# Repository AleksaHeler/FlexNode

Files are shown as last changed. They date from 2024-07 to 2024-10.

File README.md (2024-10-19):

# FlexNode

FlexNode is a DIY "smart home" system with a single hub and multiple flexible and customizable nodes.

## System Diagram

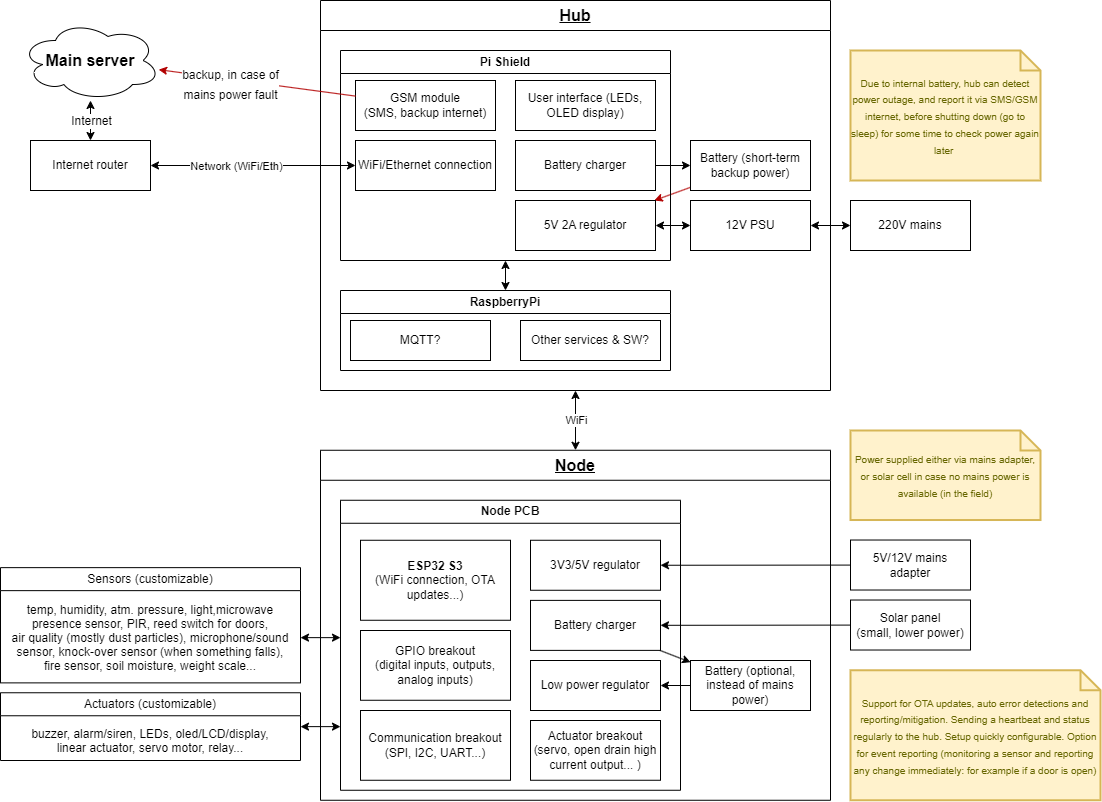
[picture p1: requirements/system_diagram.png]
system requirement diagram


### Node proof of concept

Some images during building:
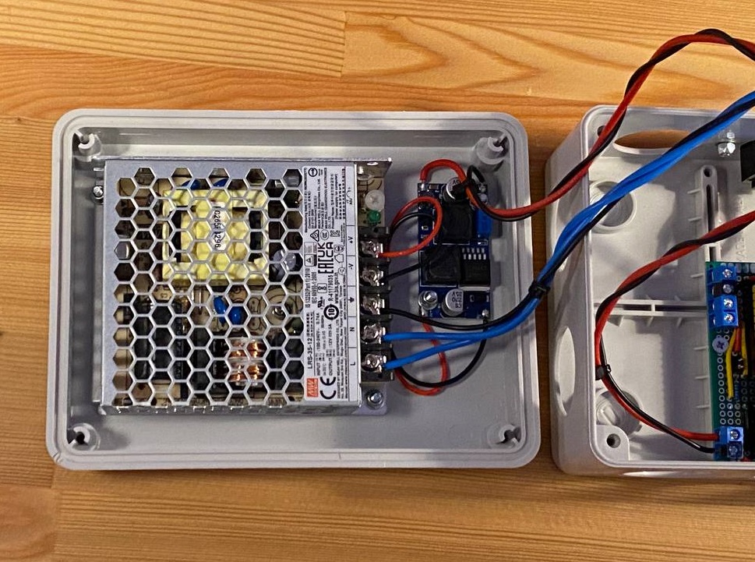
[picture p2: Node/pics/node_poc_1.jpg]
proof of concept build #1

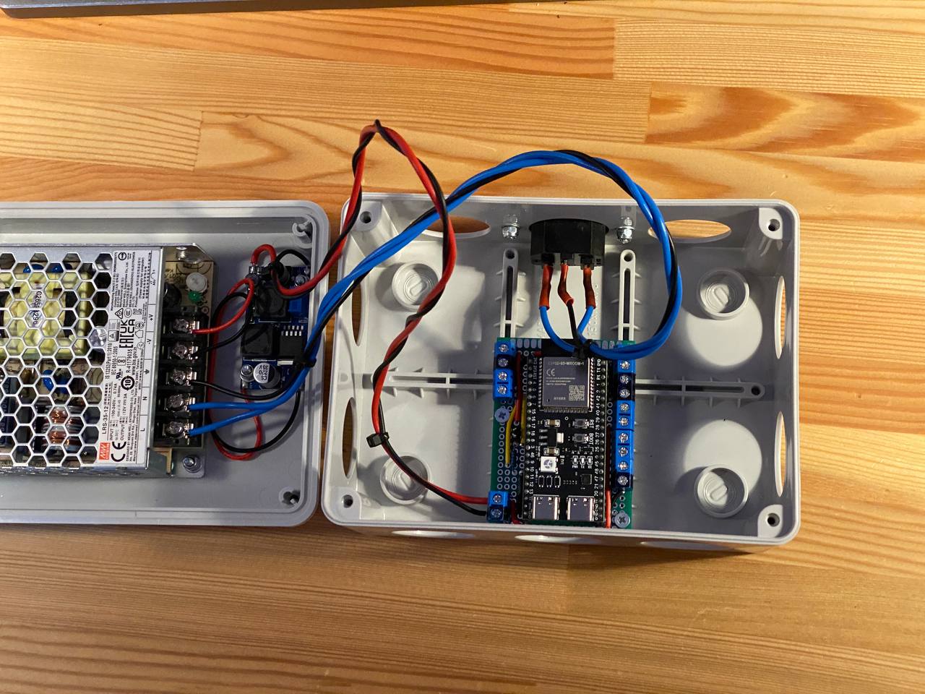
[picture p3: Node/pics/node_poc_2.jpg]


Grafana screenshots showing it in action:
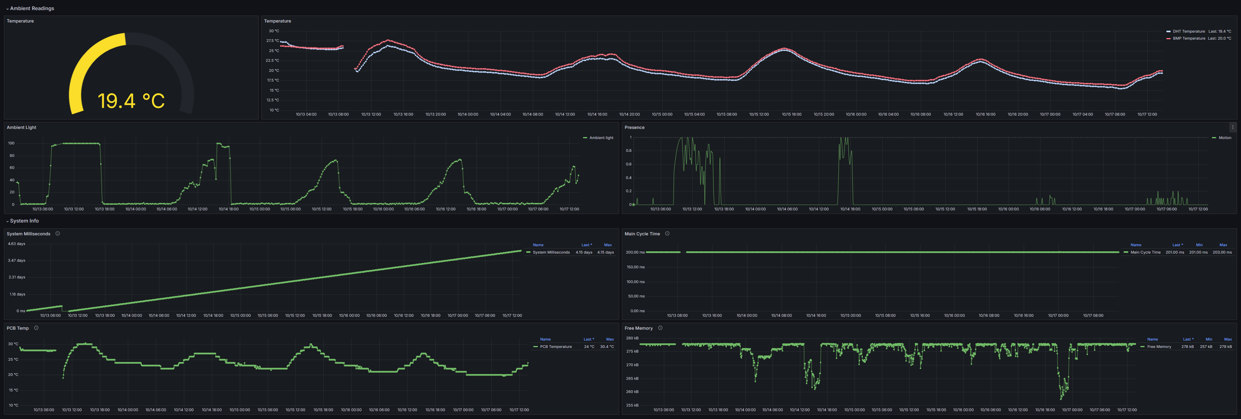
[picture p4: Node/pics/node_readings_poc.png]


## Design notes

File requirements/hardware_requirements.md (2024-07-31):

# Hardware requirements

## Hub
 - Shield for RaspberryPi
 - Integrated small battery, and on-board battery charger (what type of battery? how many cells? possibly small bike battery?)
   - On power loss, use backup battery to send warning of power outage
 - GSM module for SMS and backup internet
 - All in a single box, using wifi, or even ethernet connection to a router
 - Input voltage range for example 12-36V, which is stepped down to charge the battery and to run Pi. On power loss, able to detect
   main supply is out, but continue working on battery for some time to send last message

### Hub component selection
 - Battery?
 - Charger IC for the battery?
 - GSM module?
 - Power regulation, buck converter?
 - ...

## Node
 - Main processor: ESP32 S3 module
 - Option for adding a battery and a charger - find suitable ICs, and low power LDO regulator
 - How many cells (most likely one cell li-ion, 4.2V charging)
 - Input power from a small solar panel to charge the battery
 - All in a box (except solar cell, to be positioned at best angle)
 - Option to run in ultra low power mode (at least 1 month without any additional charge)
 - WiFi communication to the Hub + Over The Air updates (OTA)
 - Couple of on-board sensors and feedbacks
 - As many GPIO outputs as possible - for external sensors/actuators
 - All comms: SPI, I2C, UART... break out to connectors
 - What actuators will we have? What are the power requirements?
   - H bridge? servo output? DC motor output? Relay/SSR output? What will be on the PCB, and what connected externally within the box
 - Example sensor inputs (3x 1wire, 3x I2C, 4x ADC, 5x dig in):
   - temp - 1 wire
   - humidity - 1 wire
   - atm. pressure - I2C, 1 wire
   - light - analog input
   - microwave presence sensor - dig in
   - PIR - dig in
   - reed switch for doors - dig in
   - air quality (mostly dust particles) - I2C
   - microphone/sound sensor - analog input
   - knock-over sensor (when something falls) - dig in
   - fire sensor - dig in/ analog input
   - soil moisture - analog input
   - weight scale - I2C
 - Example actuator outputs (5x open drain, 1x PWM, I2C):
   - buzzer - dig out, open drain
   - alarm/siren - open drain
   - LEDs - dig out, open drain
   - oled/LCD/display - I2C
   - linear actuator - open drain
   - servo motor - PWM output
   - relay - open drain
 - Based on examples:
   - 6x digital inputs/outpus (with 1wire support)
   - 4x analog inputs
   - 4x open drain, high power outputs
   - 2x PWM, servo outputs

### Node component selection
 - [ESP32 S3 WROOM 1 N16R8](https://www.lcsc.com/product-detail/WiFi-Modules_Espressif-Systems-ESP32-S3-WROOM-1-N16R8_C2913202.html)
 - Battery management IC - [MCP73831T](https://www.lcsc.com/product-detail/span-style-background-color-ff0-Battery-span-Management_Microchip-Tech-MCP73831T-2ACI-OT_C424093.html)
 - LDO, low quiescent current 3v3 regulator - [TLV70433DBVR](https://www.lcsc.com/product-detail/Voltage-Regulators-Linear-Low-Drop-Out-span-style-background-color-ff0-LDO-span-Regulators_Texas-Instruments-TLV70433DBVR_C94917.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)
 - Low-Side Gate Driver for open drain outputs - [UCC27517](https://www.lcsc.com/product-detail/Gate-Drivers_Texas-Instruments-UCC27517DBVR_C99395.html)
 - Battery: 1 cell LiIon
 - Screw terminals
 - Battery

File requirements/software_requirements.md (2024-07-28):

# Software requirements

## Hub
 - RaspberryPi + DIY shield for Pi
 - On power loss, use backup battery to send warning of power outage
 - Use existing WiFi networks (but possibility to use GSM module for standalone operation)
 - Uploads all data to main server, which is hosted somewhere else
 
## Node
 - DIY PCB, with ESP32 S3 module
 - Many different sensor/actuator options
 - Option to run in ultra low power mode, with battery and solar panel options 
   (for installing in locations without power supply)
 - WiFi communication to the Hub
 - Modular - same PCB/HW, almost same SW (just config different) for all possible scenarios
 - Over The Air updates (OTA)
 - Option to monitor sensors constanly (alarm function)
 - Periodic wakeup, gather data, send to Hub
 - Configurable via simple config file
 - Sending a heartbeat signal to the hub if necessary, also status (starting up, shutting down...)
 - Auto error detections and mitigations (resets, sending a warning/error, self shutdown...)
 - Possible sensors: temp, humidity, atm. pressure, light, microwave presence sensor, PIR,
   reed switch for doors, air quality (mostly dust particles), microphone/sound sensor,
   knock-over sensor (when something falls), fire sensor, soil moisture, weight scale...
 - Possible actuators: buzzer, alarm/siren, LEDs, oled/LCD/display, linear actuator, servo motor, relay...

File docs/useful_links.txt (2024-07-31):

https://docs.espressif.com/projects/esp-idf/en/stable/esp32s3/api-reference/system/sleep_modes.html

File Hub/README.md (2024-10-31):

# Hub

Raspberry Pi 3 B+, running NodeRed, InfluxDB and Grafana.

## System requirement

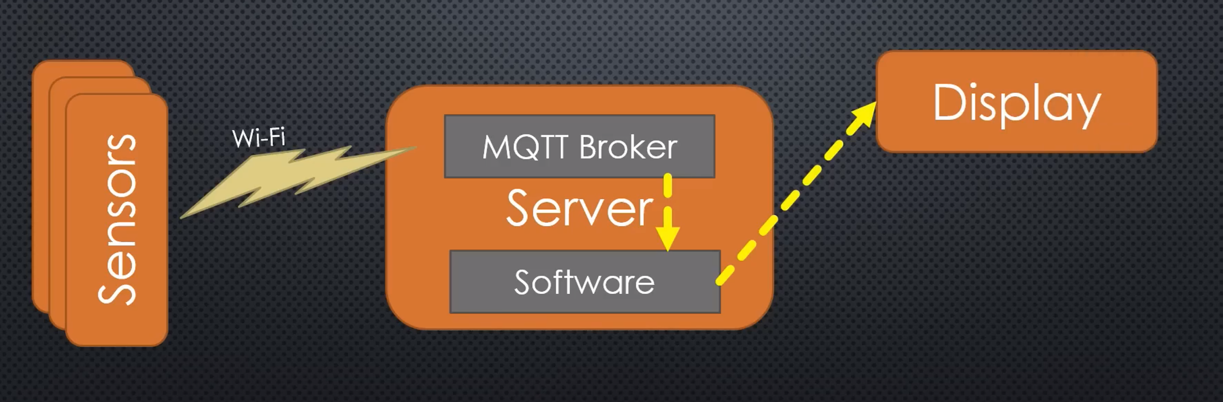
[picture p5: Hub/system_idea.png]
System reference idea


## Setup procedure

Taken from [this video](https://www.youtube.com/watch?v=I4alYbgDi4I&list=PL3XBzmAj53RnezxZ_uq8YMymURnnLTqZP&index=9)

- install raspbian lite 64bit
- enable ssh, enter wifi data and username an password
- sudo apt-get update
- sudo apt-get dist-upgrade

- now follow peter scargill's instructions for his script
- apps:
  - quiet
  - prereq
  - mosquitto
  - apache
  - nodenew
  - java
  - phpsysinfo
  - modpass
  - addindex
  - rpiclone
  - log2ram
  - grafana
  - wolfram
  - office

- sudo nano /etc/influxdb/influxdb.conf (HTTP enable, and bind to standard port)
- create admin user
- check if grafana and nodered work
- todo: change from default ports, to use url/grafana and url/nodered (not port :3000, that should be blocked)

- Hearbeat signal / watchdog
  https://www.youtube.com/watch?v=IGB2eRvhvB0&list=PL3XBzmAj53RnezxZ_uq8YMymURnnLTqZP&index=10

- Add users to MQTT (for esp32 that will be connected) with command:
  > cd /etc/mosquitto/
  > mosquitto_passwd -c passwords user
  Now you can use this command to add additional users to the file:
  > mosquitto_passwd -b passwords user password
  And check all the passwords:
  > cat passwords

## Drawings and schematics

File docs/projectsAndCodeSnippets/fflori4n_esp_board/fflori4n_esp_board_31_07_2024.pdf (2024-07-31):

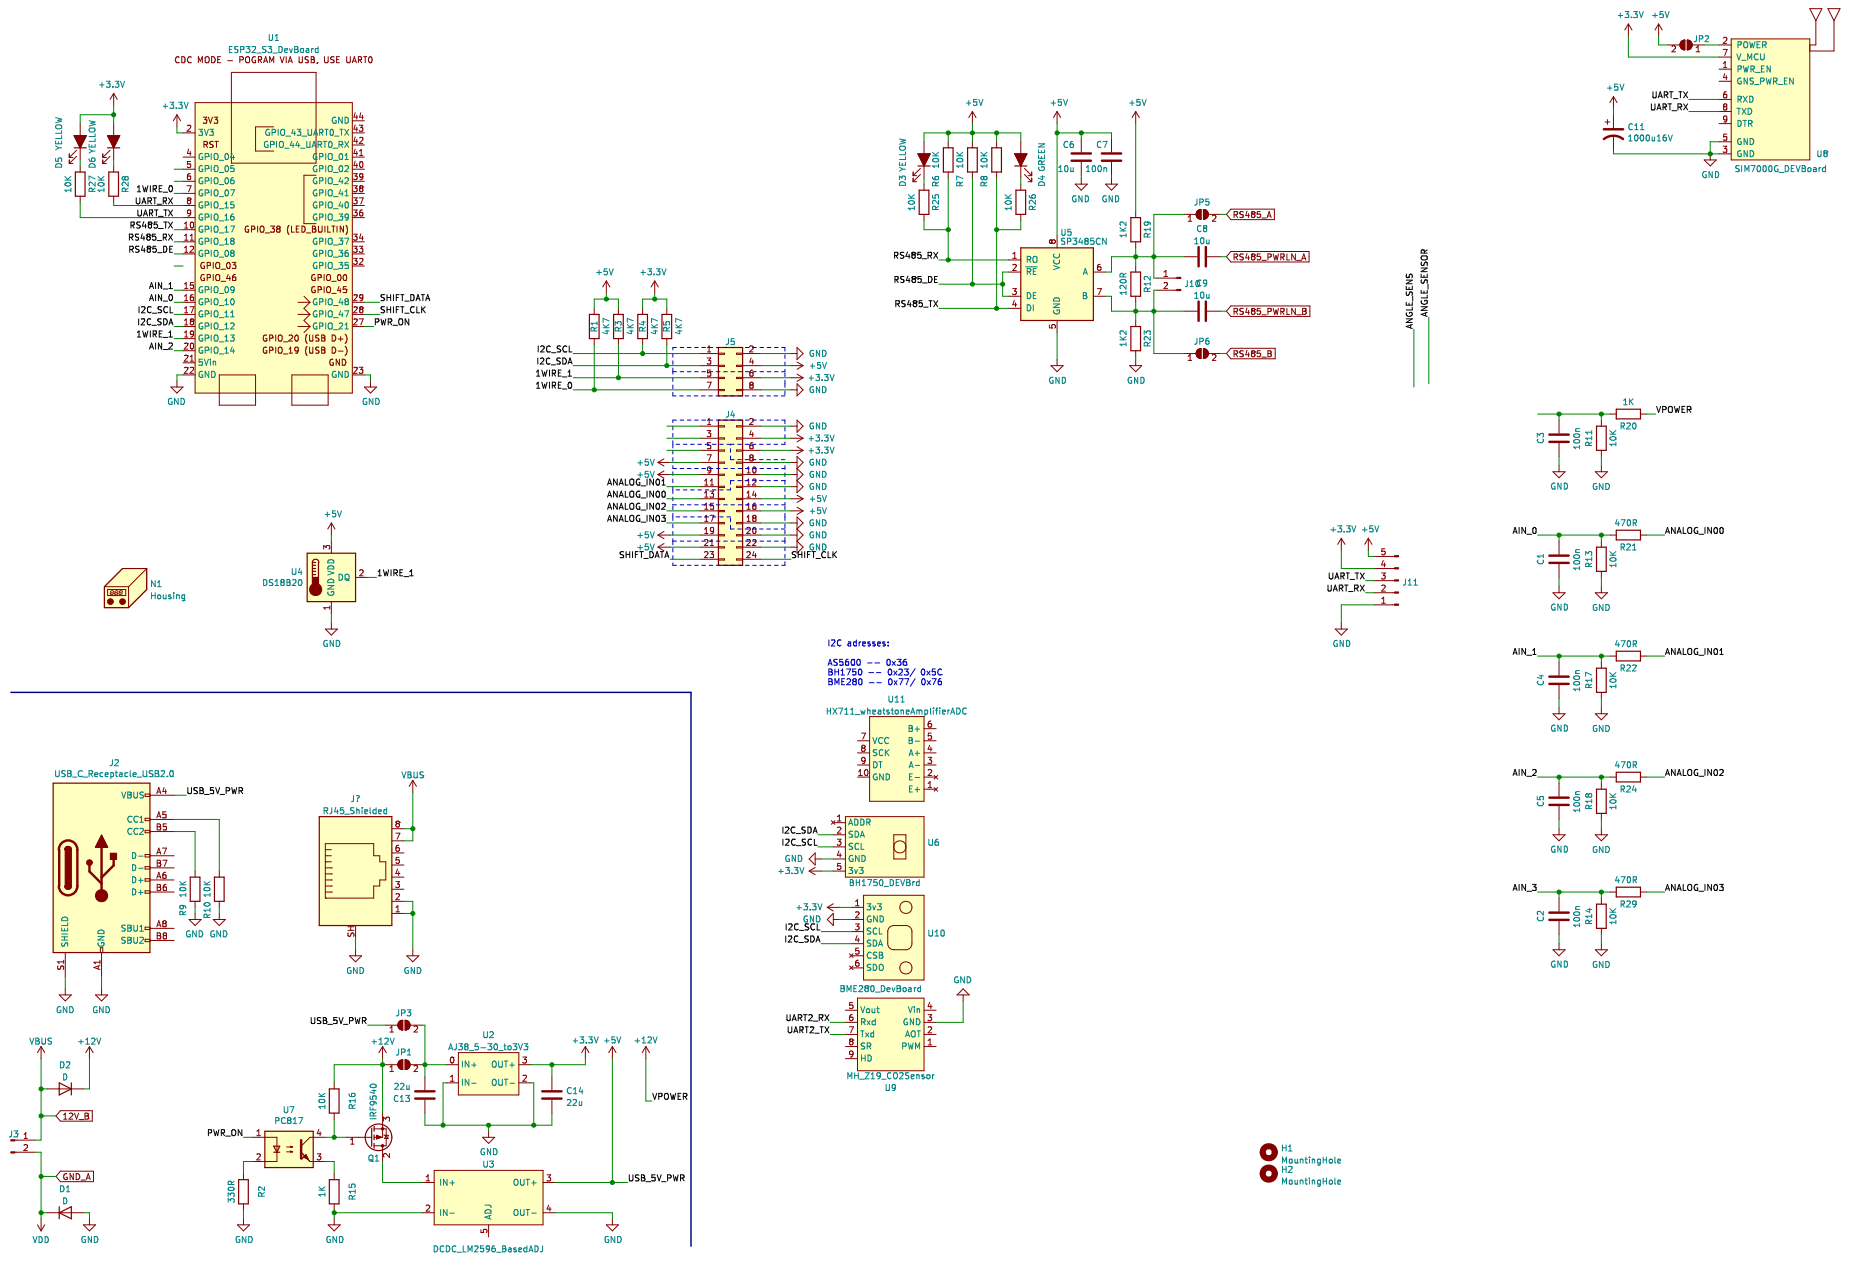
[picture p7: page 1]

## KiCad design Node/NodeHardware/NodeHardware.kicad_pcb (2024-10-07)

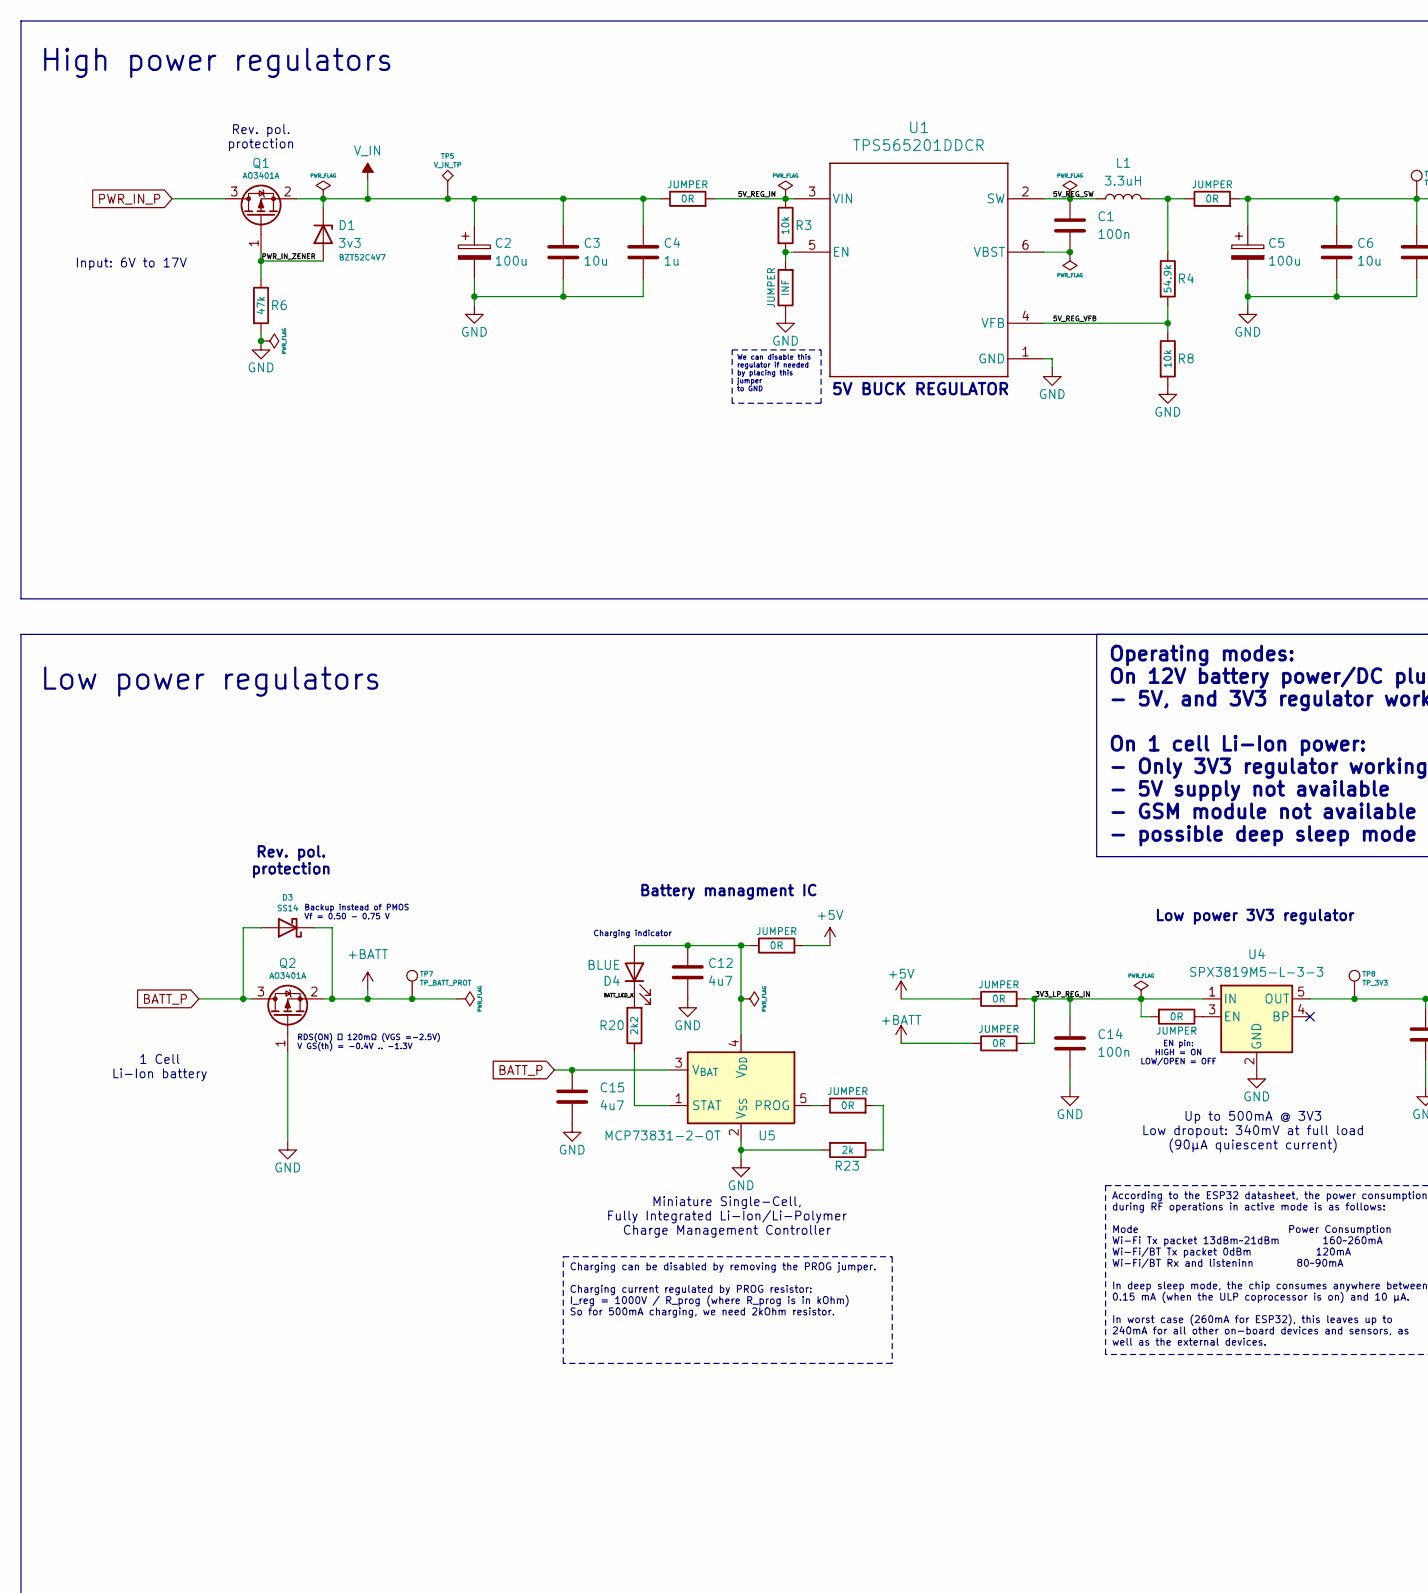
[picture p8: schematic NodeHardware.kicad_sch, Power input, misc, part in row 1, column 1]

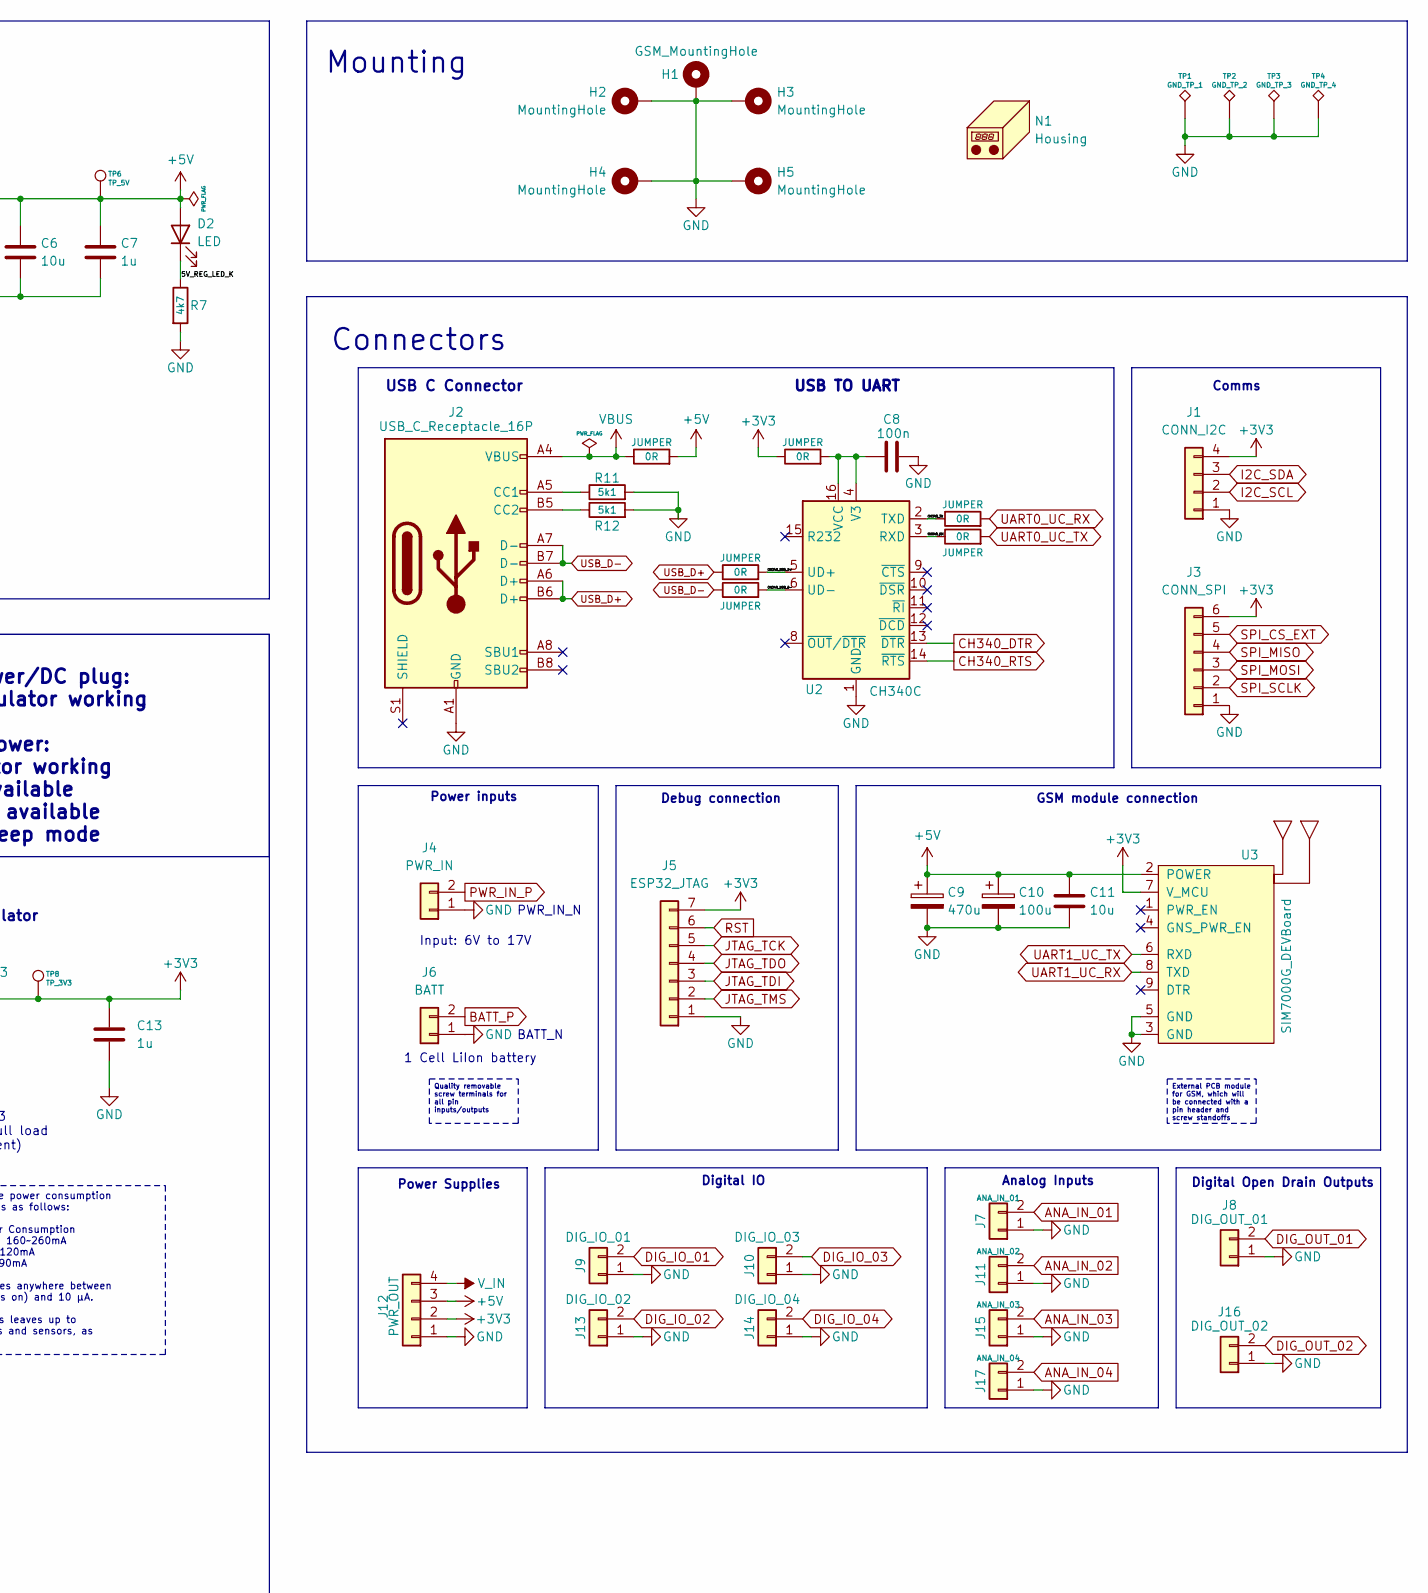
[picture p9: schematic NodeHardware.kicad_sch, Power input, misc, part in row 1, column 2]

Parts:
C1, C8, C14: 100n; C_0805_2012Metric
C2, C5, C10: 100u; CP_Elec_6.3x7.7
C3, C6, C11: 10u; C_0805_2012Metric
C4, C7, C13: 1u; C_0805_2012Metric
C9: 470u; CP_Elec_6.3x7.7
C12, C15: 4u7; C_0805_2012Metric
D1: 3v3; D_SOD-123; Part Name BZT52C4V7
D2: LED; LED_1210_3225Metric
D3: SS14; D_SMA
D4: BLUE; LED_1210_3225Metric
H1: GSM_MountingHole; MountingHole_3.2mm_M3_Pad_Via
H2, H3, H4, H5: MountingHole; MountingHole_3.2mm_M3_Pad_Via
J1: CONN_I2C; TerminalBlock_bornier-4_P5.08mm
J2: USB_C_Receptacle_16P; USB_C_Receptacle_G-Switch_GT-USB-7010ASV
J3: CONN_SPI; TerminalBlock_bornier-6_P5.08mm
J4: PWR_IN; TerminalBlock_bornier-2_P5.08mm
J5: ESP32_JTAG; PinHeader_1x07_P2.54mm_Vertical
J6: BATT; TerminalBlock_bornier-2_P5.08mm
J7: ANA_IN_01; TerminalBlock_bornier-2_P5.08mm
J8: DIG_OUT_01; TerminalBlock_bornier-2_P5.08mm
J9: DIG_IO_01; TerminalBlock_bornier-2_P5.08mm
J10: DIG_IO_03; TerminalBlock_bornier-2_P5.08mm
J11: ANA_IN_02; TerminalBlock_bornier-2_P5.08mm
J12: PWR_OUT; TerminalBlock_bornier-4_P5.08mm
J13: DIG_IO_02; TerminalBlock_bornier-2_P5.08mm
J14: DIG_IO_04; TerminalBlock_bornier-2_P5.08mm
J15: ANA_IN_03; TerminalBlock_bornier-2_P5.08mm
J16: DIG_OUT_02; TerminalBlock_bornier-2_P5.08mm
J17: ANA_IN_04; TerminalBlock_bornier-2_P5.08mm
L1: 3.3uH; L_6.3x6.3_H3
N1: Housing; PlasticEnclosure_150x110x70
Q1, Q2: AO3401A; SOT-23
R1, R2, R9, R10, R13, R14, R15, R16, R17, R18, R19, R21, R22: 0R; R_0805_2012Metric
R3, R8: 10k; R_0805_2012Metric
R4: 54.9k; R_0805_2012Metric
R5: INF; R_0805_2012Metric
R6: 47k; R_0805_2012Metric
R7: 4k7; R_0805_2012Metric
R11, R12: 5k1; R_0805_2012Metric
R20: 2k2; R_0805_2012Metric
R23: 2k; R_0805_2012Metric
TP1: GND_TP_1; TestPoint_Pad_D2.0mm
TP2: GND_TP_2; TestPoint_Pad_D2.0mm
TP3: GND_TP_3; TestPoint_Pad_D2.0mm
TP4: GND_TP_4; TestPoint_Pad_D2.0mm
TP5: V_IN_TP; TestPoint_Pad_D2.0mm
TP6: TP_5V; TestPoint_Pad_D2.0mm
TP7: TP_BATT_PROT; TestPoint_Pad_D2.0mm
TP8: TP_3V3; TestPoint_Pad_D2.0mm
U1: TPS565201DDCR; TPS565201DDCR_L
U2: CH340C; SOIC-16_3.9x9.9mm_P1.27mm
U3: SIM7000G_DEVBoard; sim7000G_dev_board_rev3
U4: SPX3819M5-L-3-3; SOT-23-5
U5: MCP73831-2-OT; SOT-23-5

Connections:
+3V3: C13.1, J1.4, J3.6, J5.7, J12.2, R10.1, TP8.1, U3.7 (V_MCU), U4.5 (OUT); also elsewhere on the board
+5V: C5.1, C6.1, C7.1, C9.1, C10.1, C11.1, D2.2 (A), J12.3, R2.2, R9.2, R17.2, R18.1, TP6.1, U3.2 (POWER); also elsewhere on the board
+BATT: D3.1 (K), Q2.2 (S), R21.1, TP7.1; also elsewhere on the board
/3V3_LP_REG_IN: C14.1, R18.2, R19.2, R21.2, U4.1 (IN)
/5V_REG_IN: R1.2, R3.1, U1.3 (VIN)
/5V_REG_LED_K: D2.1 (K), R7.1
/5V_REG_SW: C1.1, L1.1, U1.2 (SW)
/5V_REG_VFB: R4.2, R8.1, U1.4 (VFB)
/BATT_LED_K: D4.1 (K), R20.2
/CH340_RX: R14.1, U2.3 (RXD)
/CH340_TX: R13.1, U2.2 (TXD)
/CH340_USB_D+: R15.2, U2.5 (UD+)
/CH340_USB_D-: R16.2, U2.6 (UD-)
/PWR_IN_ZENER: D1.2 (A), Q1.1 (G), R6.1
ANA_IN_01: J7.2; also elsewhere on the board
ANA_IN_02: J11.2; also elsewhere on the board
ANA_IN_03: J15.2; also elsewhere on the board
ANA_IN_04: J17.2; also elsewhere on the board
BATT_P: C15.1, D3.2 (A), J6.2, Q2.3 (D), U5.3 (V_{BAT})
CH340_DTR: U2.13 (~DTR); also elsewhere on the board
CH340_RTS: U2.14 (~RTS); also elsewhere on the board
DIG_IO_01: J9.2; also elsewhere on the board
DIG_IO_02: J13.2; also elsewhere on the board
DIG_IO_03: J10.2; also elsewhere on the board
DIG_IO_04: J14.2; also elsewhere on the board
DIG_OUT_01: J8.2; also elsewhere on the board
DIG_OUT_02: J16.2; also elsewhere on the board
GND: C2.2, C3.2, C4.2, C5.2, C6.2, C7.2, C8.2, C9.2, C10.2, C11.2, C12.2, C13.2, C14.2, C15.2, H1.1, H2.1, H3.1, H4.1, H5.1, J1.1, J2.A1 (GND), J2.A12 (GND), J2.B1 (GND), J2.B12 (GND), J3.1, J4.1, J5.1, J6.1, J7.1, J8.1, J9.1, J10.1, J11.1, J12.1, J13.1, J14.1, J15.1, J16.1, J17.1, Q2.1 (G), R5.1, R6.2, R7.2, R8.2, R11.2, R12.2, R23.2, TP1.1, TP2.1, TP3.1, TP4.1, U1.1 (GND), U2.1 (GND), U3.3 (GND), U3.5 (GND), U4.2 (GND), U5.2 (V_{SS}); also elsewhere on the board
I2C_SCL: J1.2; also elsewhere on the board
I2C_SDA: J1.3; also elsewhere on the board
JTAG_TCK: J5.5; also elsewhere on the board
JTAG_TDI: J5.3; also elsewhere on the board
JTAG_TDO: J5.4; also elsewhere on the board
JTAG_TMS: J5.2; also elsewhere on the board
unnamed: C12.1, D4.2 (A), R17.1, U5.4 (V_{DD})
unnamed: J2.A5 (CC1), R11.1
unnamed: J2.B5 (CC2), R12.1
unnamed: L1.2, R2.1, R4.1
unnamed: R22.2, R23.1
unnamed: R3.2, R5.2, U1.5 (EN)
unnamed: C1.2, U1.6 (VBST)
unnamed: C8.1, R10.2, U2.4 (V3), U2.16 (VCC)
unnamed: R19.1, U4.3 (EN)
unnamed: R22.1, U5.5 (PROG)
unnamed: R20.1, U5.1 (STAT)
PWR_IN_P: J4.2, Q1.3 (D)
RST: J5.6; also elsewhere on the board
SPI_CS_EXT: J3.5; also elsewhere on the board
SPI_MISO: J3.4; also elsewhere on the board
SPI_MOSI: J3.3; also elsewhere on the board
SPI_SCLK: J3.2; also elsewhere on the board
UART0_UC_RX: R13.2; also elsewhere on the board
UART0_UC_TX: R14.2; also elsewhere on the board
UART1_UC_RX: U3.8 (TXD); also elsewhere on the board
UART1_UC_TX: U3.6 (RXD); also elsewhere on the board
USB_D+: J2.A6 (D+), J2.B6 (D+), R15.1; also elsewhere on the board
USB_D-: J2.A7 (D-), J2.B7 (D-), R16.1; also elsewhere on the board
VBUS: J2.A4 (VBUS), J2.A9 (VBUS), J2.B4 (VBUS), J2.B9 (VBUS), R9.1
V_IN: C2.1, C3.1, C4.1, D1.1 (K), J12.4, Q1.2 (S), R1.1, TP5.1; also elsewhere on the board

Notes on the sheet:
We can disable this regulator if needed by placing this jumper to GND
External PCB module for GSM, which will be connected with a pin header and screw standoffs
Quality removable screw terminals for all pin inputs/outputs
Charging can be disabled by removing the PROG jumper. Charging current regulated by PROG resistor: I_reg = 1000V / R_prog (where R_prog is in kOhm) So for 500mA charging, we need 2kOhm resistor.
Operating modes: On 12V battery power/DC plug: - 5V, and 3V3 regulator working On 1 cell Li-Ion power: - Only 3V3 regulator working - 5V supply not available - GSM module not available - possible deep sleep mode
According to the ESP32 datasheet, the power consumption during RF operations in active mode is as follows: Mode Power Consumption Wi-Fi Tx packet 13dBm~21dBm 160~260mA Wi-Fi/BT Tx packet 0dBm 120mA Wi-Fi/BT Rx and listeninn 80~90mA In deep sleep mode, the chip consumes anywhere between 0.15 mA (whe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
Battery managment IC
1 Cell Li-Ion battery
Power Supplies
Charging indicator
Connectors
Low power 3V3 regulator
PWR_IN_N
Debug connection
Input: 6V to 17V
Power inputs
USB TO UART
Rev. pol. protection
Analog Inputs
Backup instead of PMOS Vf = 0.50 - 0.75 V
Comms
5V BUCK REGULATOR
EN pin: HIGH = ON LOW/OPEN = OFF
USB C Connector
RDS(ON) ＜ 120mΩ (VGS =-2.5V) V GS(th) = -0.4V .. -1.3V
GSM module connection
Low power regulators
Digital IO
1 Cell LiIon battery
BATT_N
Mounting
Digital Open Drain Outputs
High power regulators
Up to 500mA @ 3V3 Low dropout: 340mV at full load (90μA quiescent current)
Miniature Single-Cell, Fully Integrated Li-Ion/Li-Polymer Charge Management Controller

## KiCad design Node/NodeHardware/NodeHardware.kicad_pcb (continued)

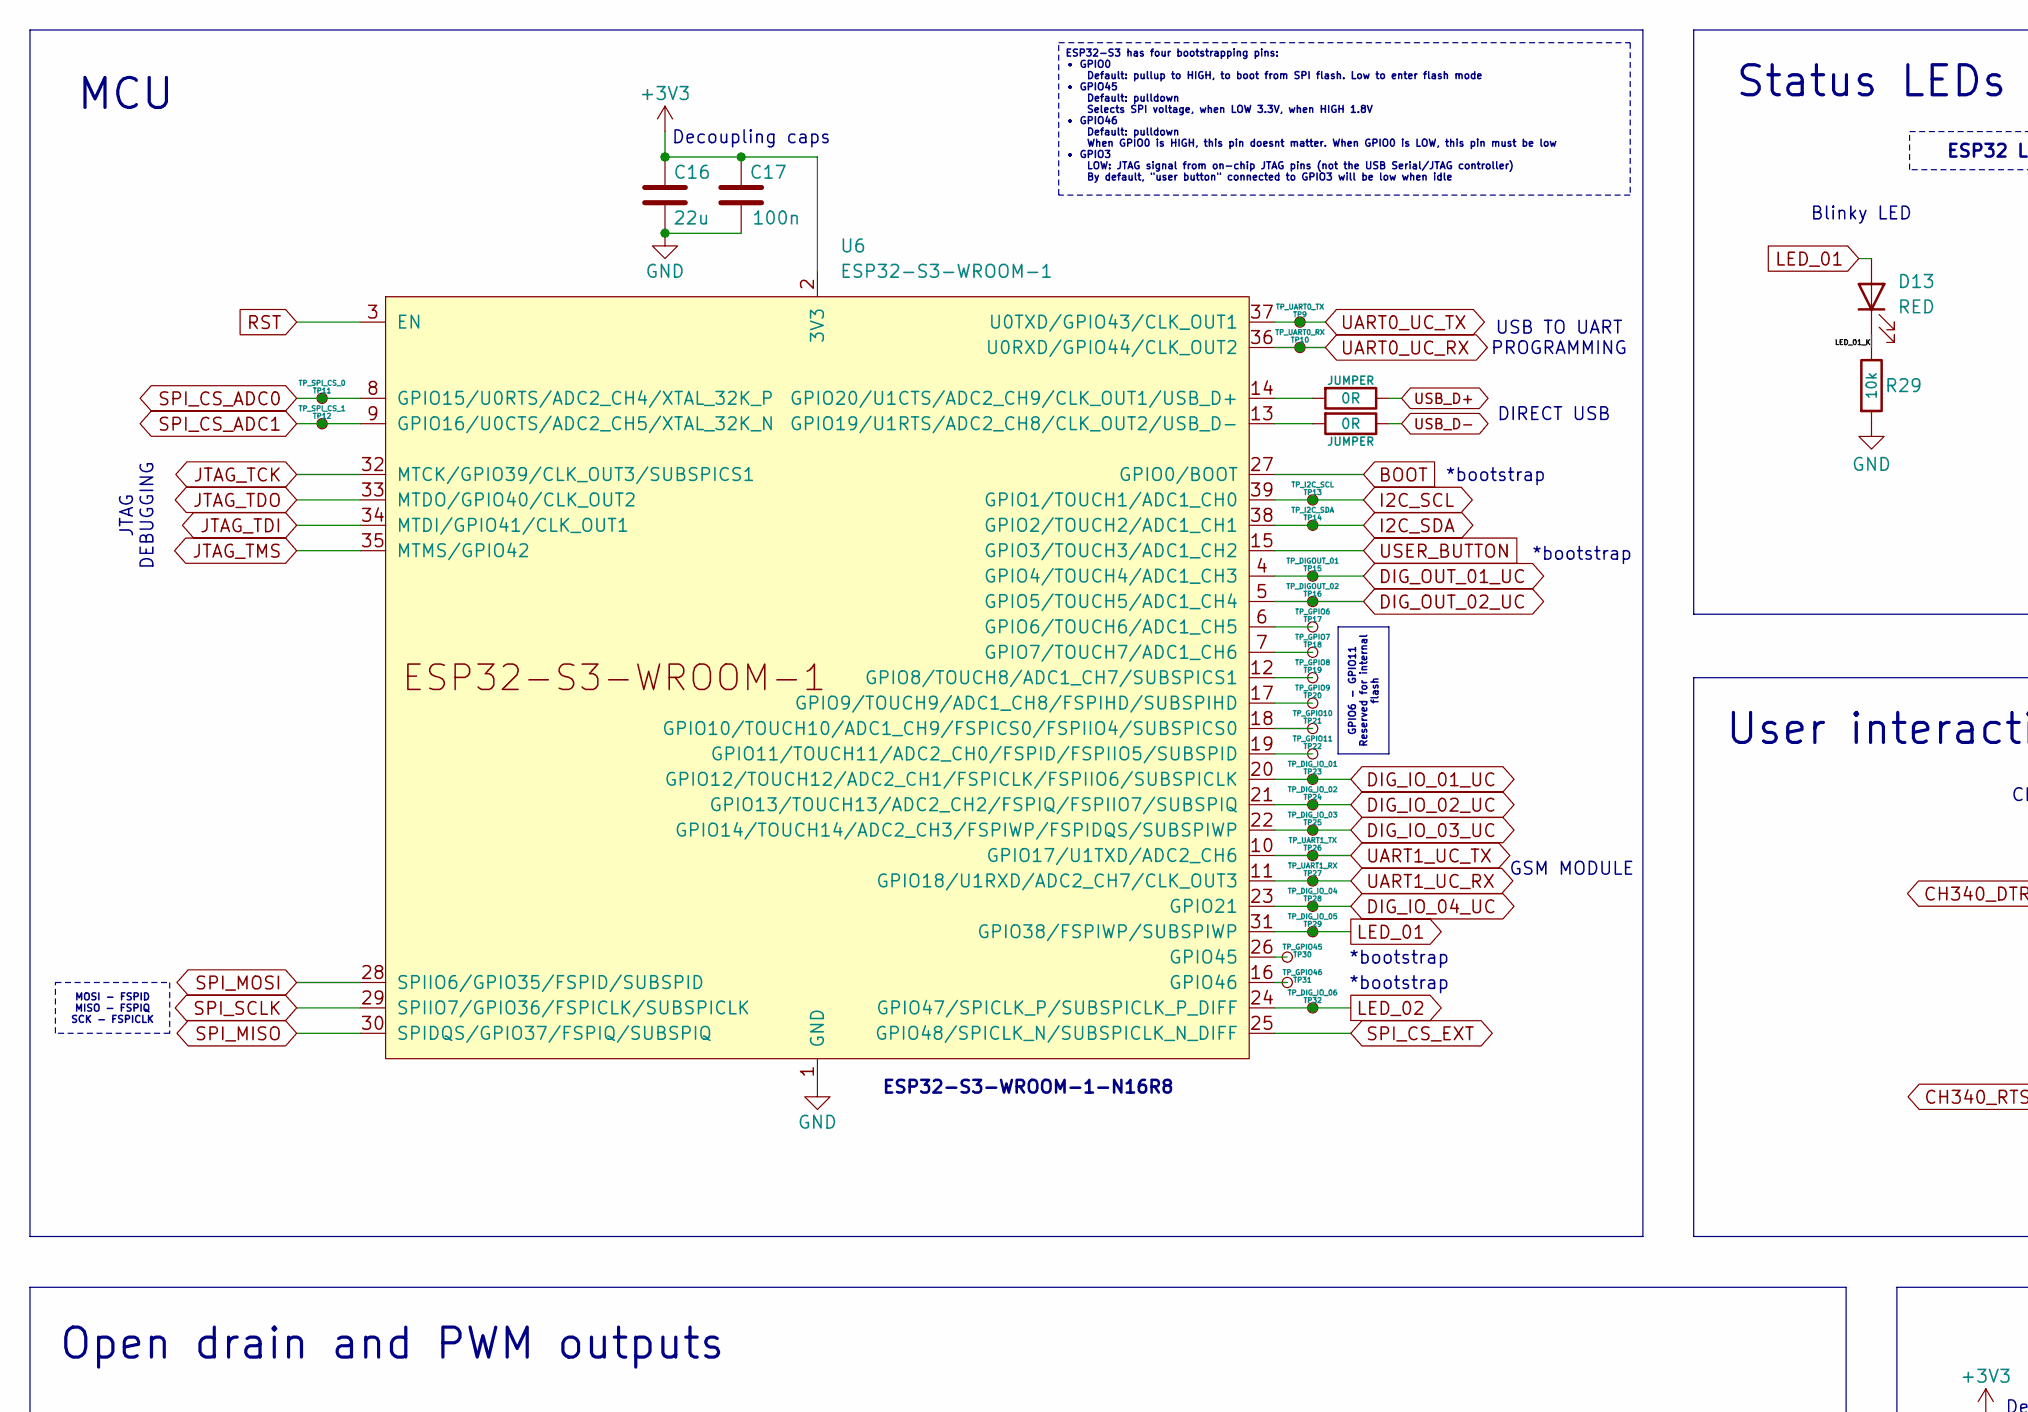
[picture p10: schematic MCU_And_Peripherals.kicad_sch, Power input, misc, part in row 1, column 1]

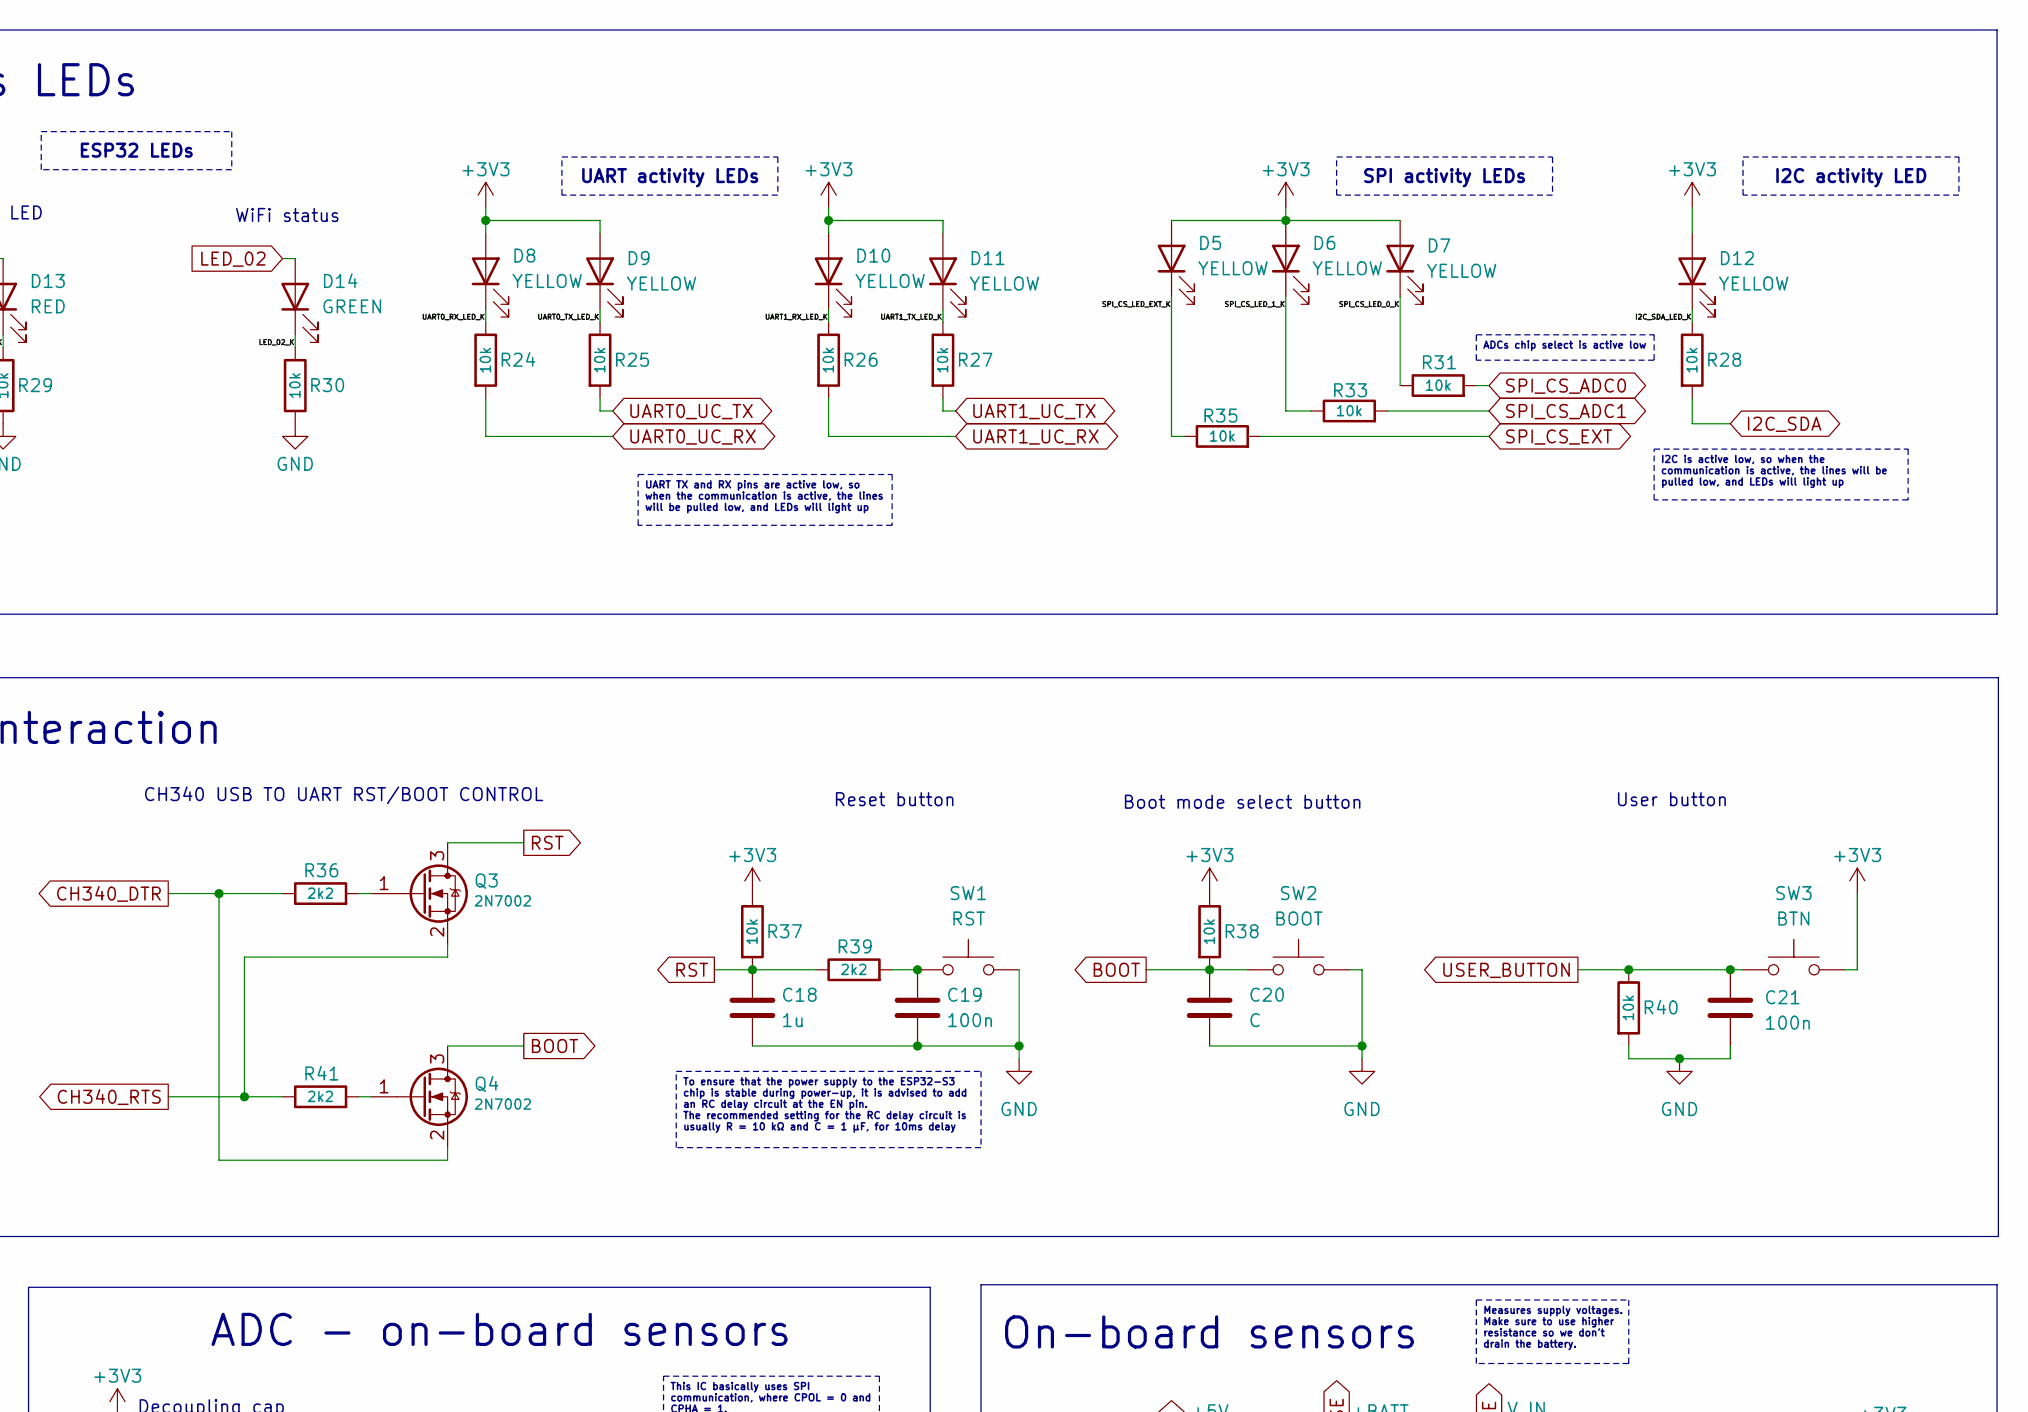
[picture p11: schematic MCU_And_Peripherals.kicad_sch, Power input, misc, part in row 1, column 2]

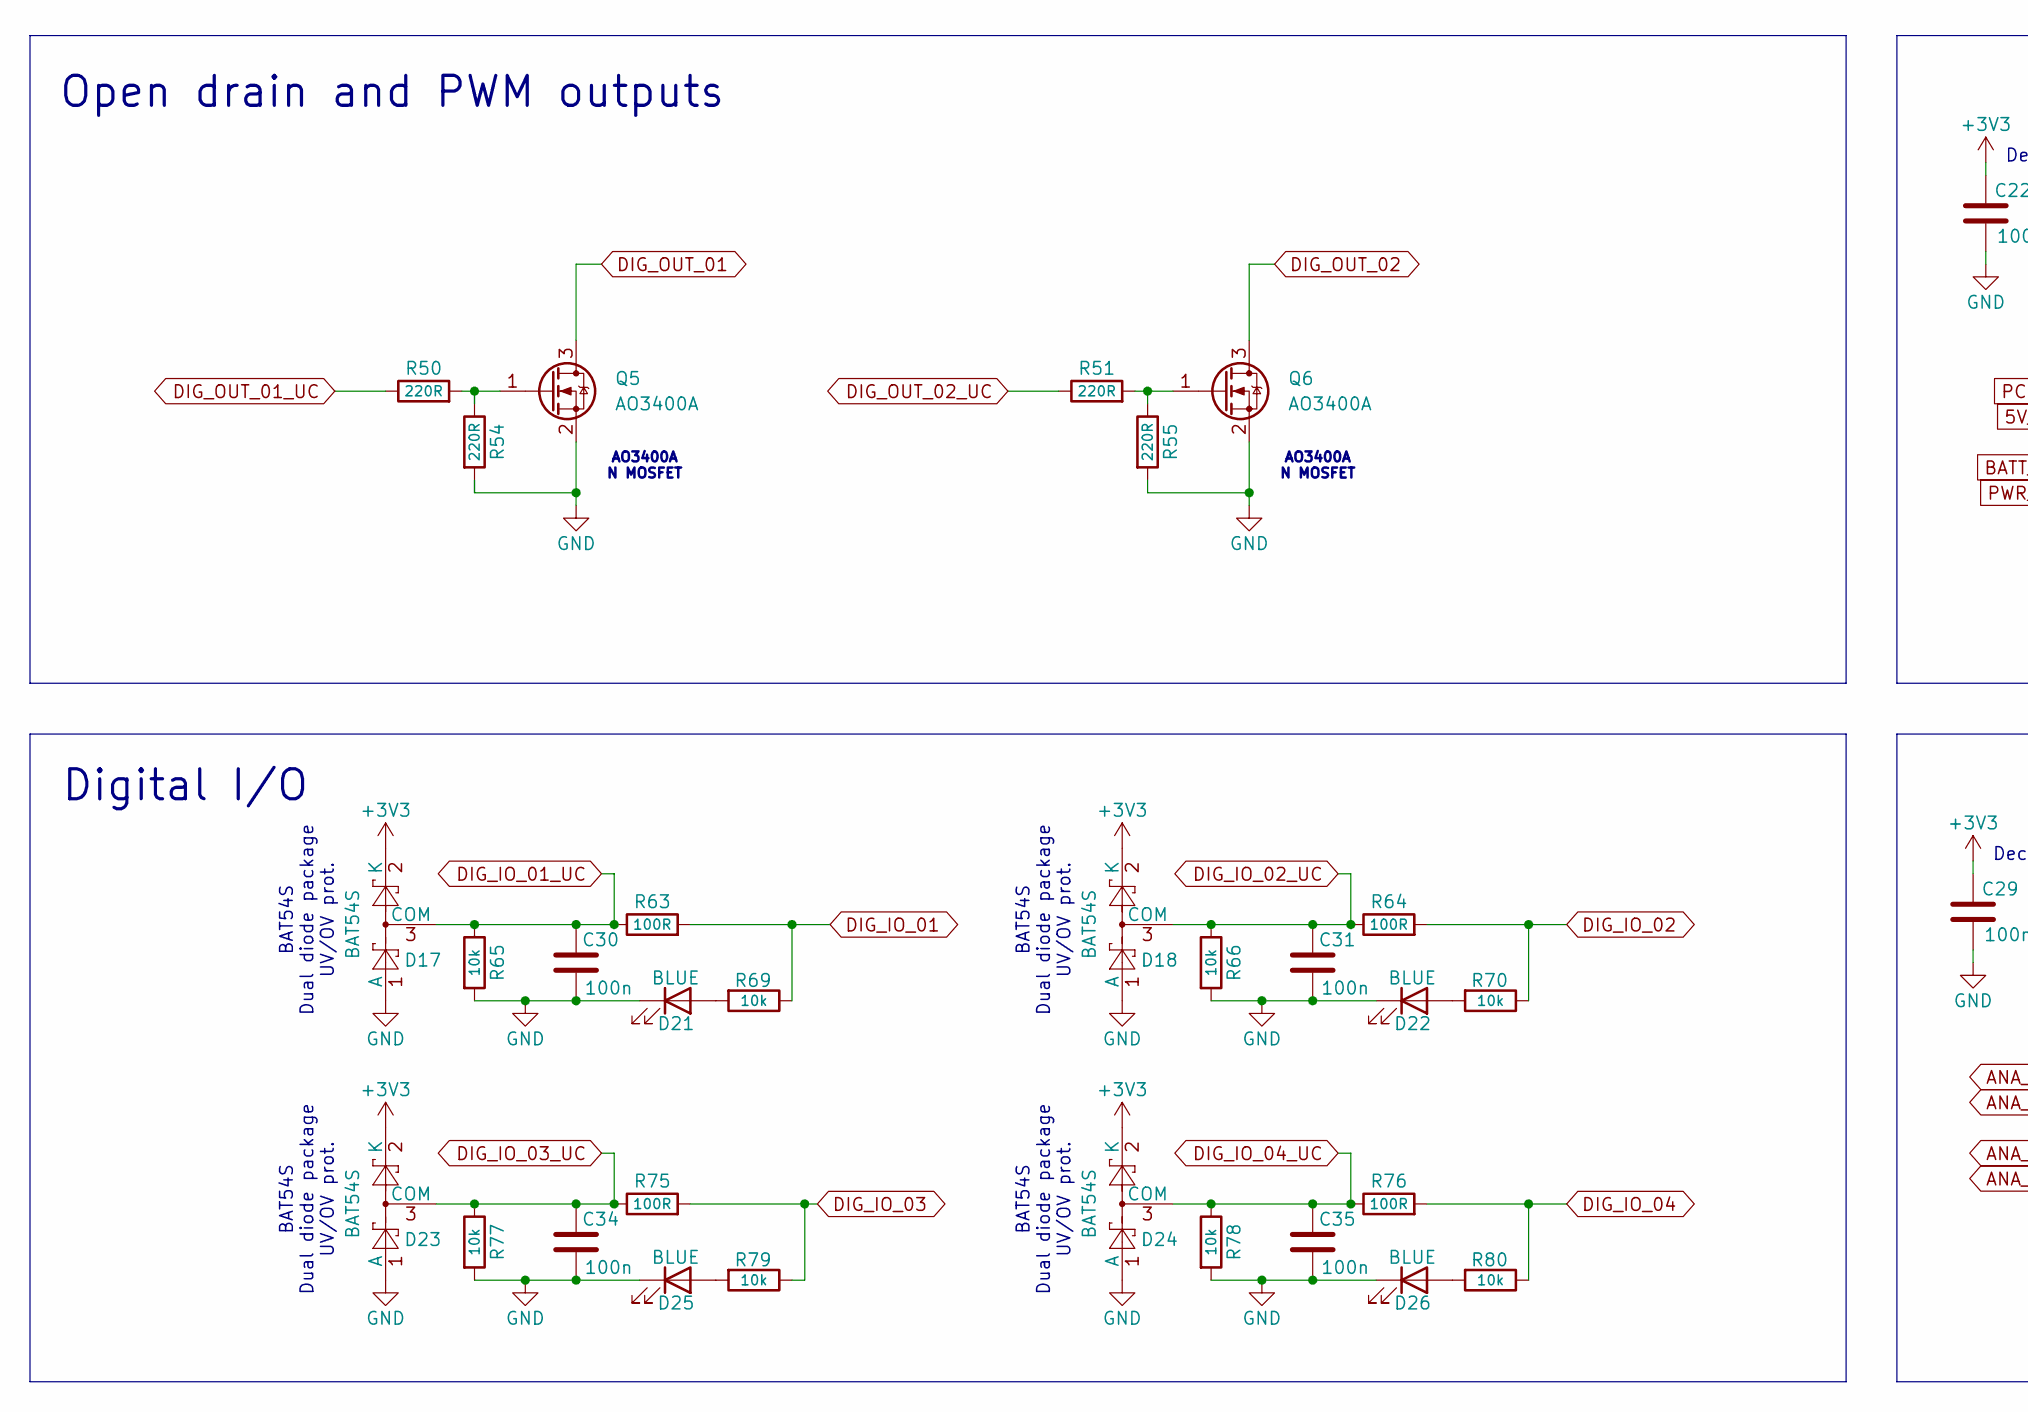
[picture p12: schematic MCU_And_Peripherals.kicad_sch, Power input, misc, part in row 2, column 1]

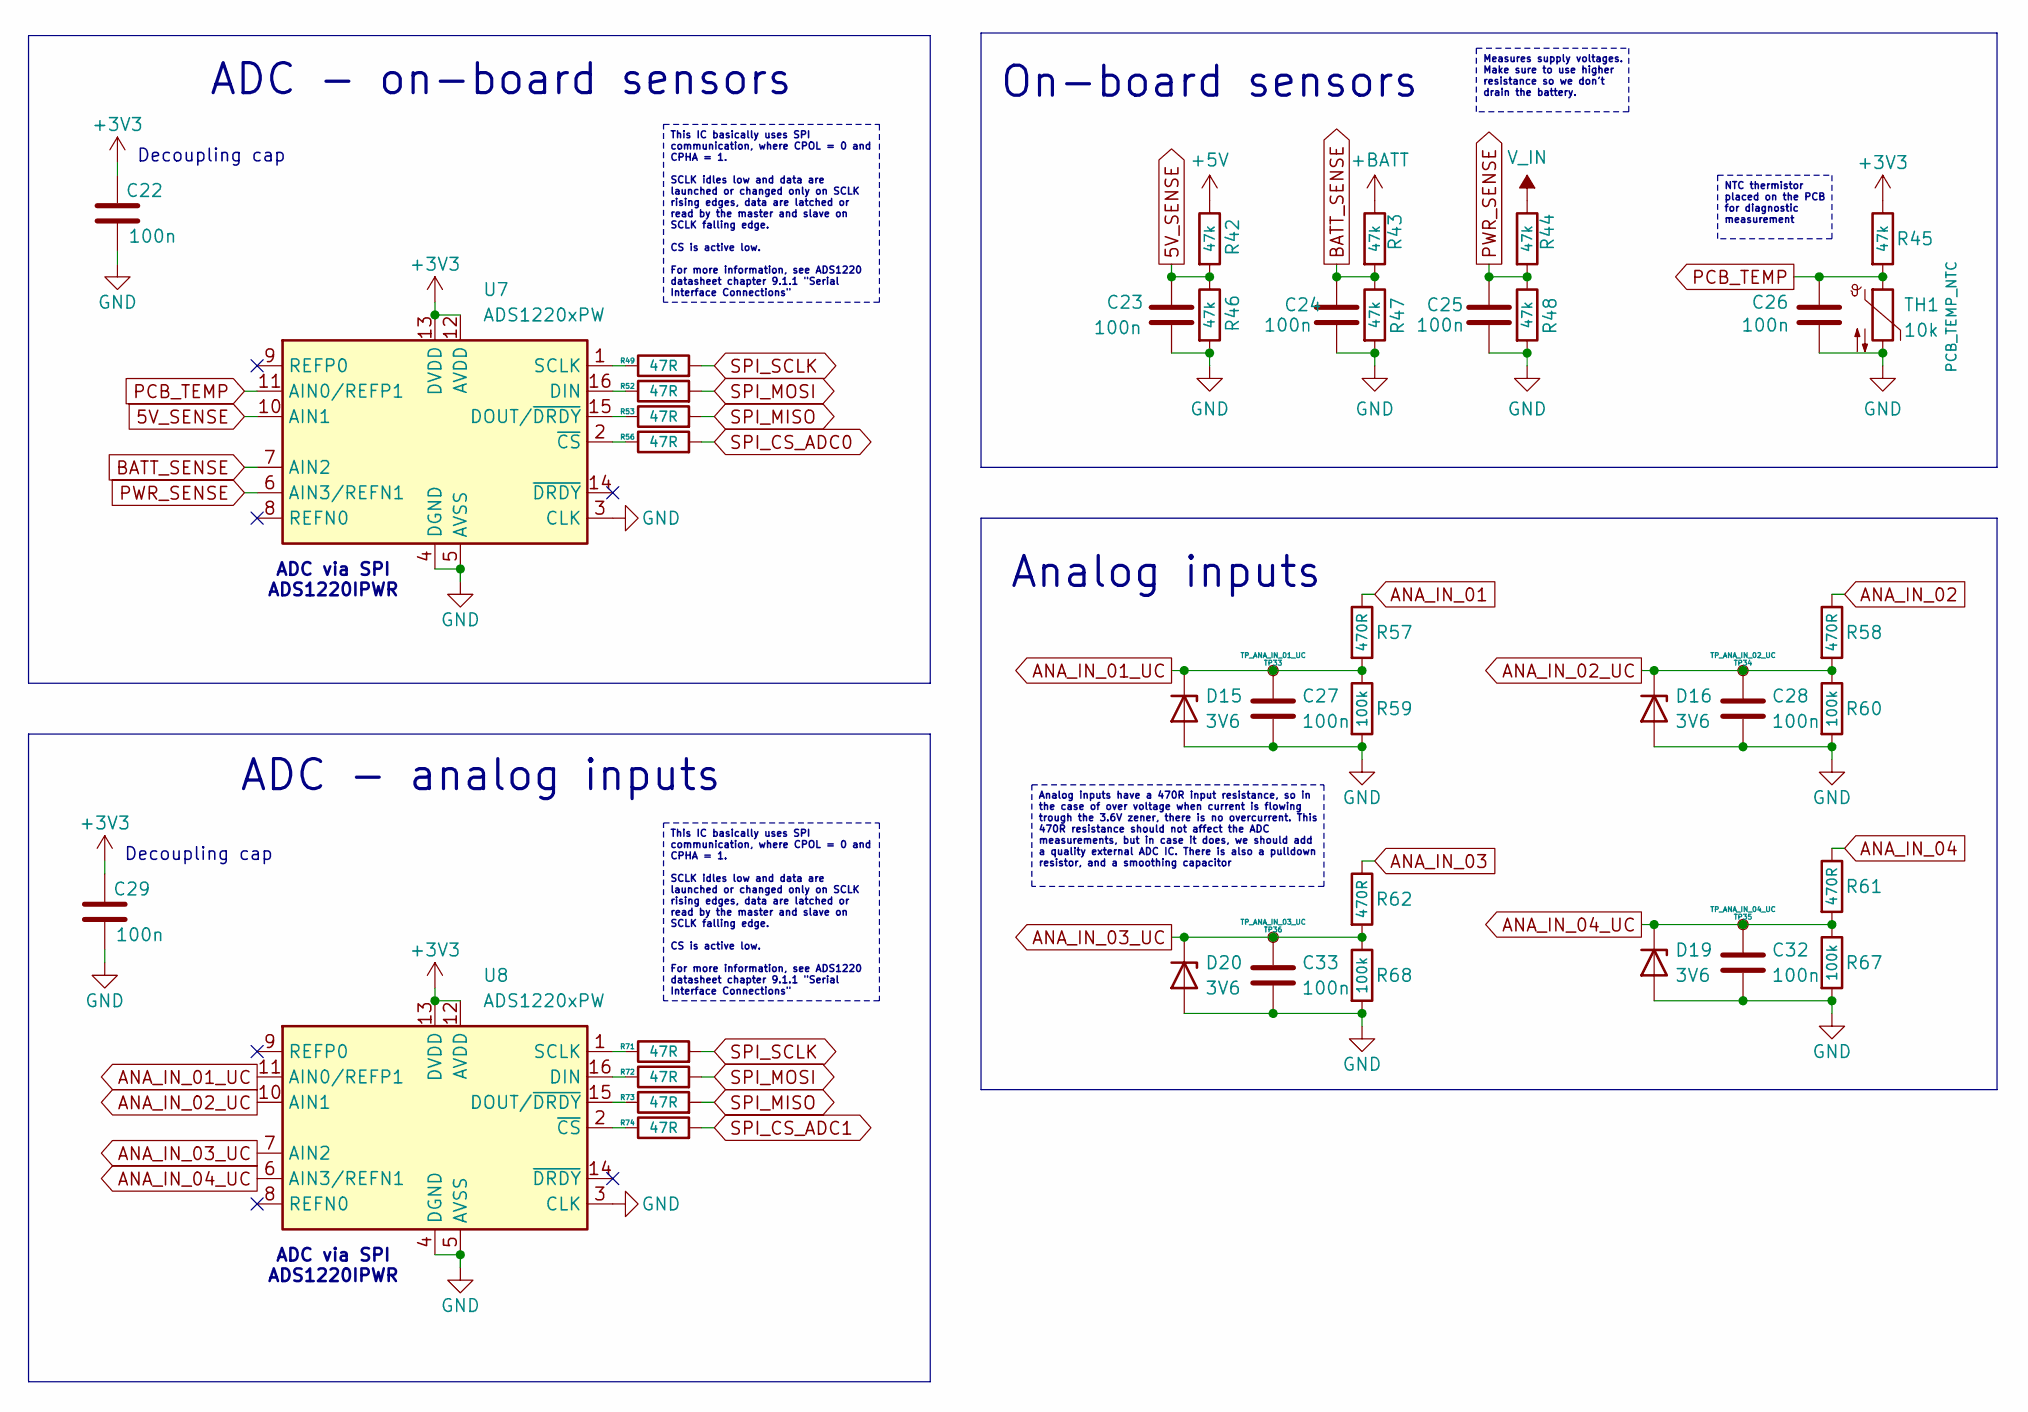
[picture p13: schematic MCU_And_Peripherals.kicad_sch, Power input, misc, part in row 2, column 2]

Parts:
C16: 22u; C_0805_2012Metric
C17, C19, C21, C22, C23, C24, C25, C26, C27, C28, C29, C30, C31, C32, C33, C34, C35: 100n; C_0805_2012Metric
C18: 1u; C_0805_2012Metric
C20: C; C_0805_2012Metric
D5, D6, D7, D8, D9, D10, D11, D12: YELLOW; LED_1210_3225Metric
D13: RED; LED_1210_3225Metric
D14: GREEN; LED_1210_3225Metric
D15, D16, D19, D20: 3V6; D_SOD-123
D17, D18, D23, D24: BAT54S; SOT-23
D21, D22, D25, D26: BLUE; LED_1210_3225Metric
Q3, Q4: 2N7002; SOT-23
Q5, Q6: AO3400A; SOT-23
R24, R25, R26, R27, R28, R29, R30, R31, R33, R35, R37, R38, R40, R65, R66, R69, R70, R77, R78, R79, R80: 10k; R_0805_2012Metric
R32, R34: 0R; R_0805_2012Metric
R36, R39, R41: 2k2; R_0805_2012Metric
R42, R43, R44, R45, R46, R47, R48: 47k; R_0805_2012Metric
R49, R52, R53, R56, R71, R72, R73, R74: 47R; R_0805_2012Metric
R50, R51, R54, R55: 220R; R_0805_2012Metric
R57, R58, R61, R62: 470R; R_0805_2012Metric
R59, R60, R67, R68: 100k; R_0805_2012Metric
R63, R64, R75, R76: 100R; R_0805_2012Metric
SW1: RST; SW_Push_1P1T_NO_6x6mm_H9.5mm
SW2: BOOT; SW_Push_1P1T_NO_6x6mm_H9.5mm
SW3: BTN; SW_Push_1P1T_NO_6x6mm_H9.5mm
TH1: 10k; R_0805_2012Metric
TP9: TP_UART0_TX; TestPoint_Pad_D1.0mm
TP10: TP_UART0_RX; TestPoint_Pad_D1.0mm
TP11: TP_SPI_CS_0; TestPoint_Pad_D1.0mm
TP12: TP_SPI_CS_1; TestPoint_Pad_D1.0mm
TP13: TP_I2C_SCL; TestPoint_Pad_D1.0mm
TP14: TP_I2C_SDA; TestPoint_Pad_D1.0mm
TP15: TP_DIGOUT_01; TestPoint_Pad_D1.0mm
TP16: TP_DIGOUT_02; TestPoint_Pad_D1.0mm
TP17: TP_GPIO6; TestPoint_Pad_D1.0mm
TP18: TP_GPIO7; TestPoint_Pad_D1.0mm
TP19: TP_GPIO8; TestPoint_Pad_D1.0mm
TP20: TP_GPIO9; TestPoint_Pad_D1.0mm
TP21: TP_GPIO10; TestPoint_Pad_D1.0mm
TP22: TP_GPIO11; TestPoint_Pad_D1.0mm
TP23: TP_DIG_IO_01; TestPoint_Pad_D1.0mm
TP24: TP_DIG_IO_02; TestPoint_Pad_D1.0mm
TP25: TP_DIG_IO_03; TestPoint_Pad_D1.0mm
TP26: TP_UART1_TX; TestPoint_Pad_D1.0mm
TP27: TP_UART1_RX; TestPoint_Pad_D1.0mm
TP28: TP_DIG_IO_04; TestPoint_Pad_D1.0mm
TP29: TP_DIG_IO_05; TestPoint_Pad_D1.0mm
TP30: TP_GPIO45; TestPoint_Pad_D1.0mm
TP31: TP_GPIO46; TestPoint_Pad_D1.0mm
TP32: TP_DIG_IO_06; TestPoint_Pad_D1.0mm
TP33: TP_ANA_IN_01_UC; TestPoint_Pad_D1.0mm
TP34: TP_ANA_IN_02_UC; TestPoint_Pad_D1.0mm
TP35: TP_ANA_IN_04_UC; TestPoint_Pad_D1.0mm
TP36: TP_ANA_IN_03_UC; TestPoint_Pad_D1.0mm
U6: ESP32-S3-WROOM-1
U7, U8: ADS1220xPW; TSSOP-16_4.4x5mm_P0.65mm

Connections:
5V_SENSE: C23.1, R42.2, R46.1, U7.10 (AIN1)
+3V3: C16.2, C17.2, C22.2, C29.2, D5.2 (A), D6.2 (A), D7.2 (A), D8.2 (A), D9.2 (A), D10.2 (A), D11.2 (A), D12.2 (A), D17.2 (K), D18.2 (K), D23.2 (K), D24.2 (K), R37.1, R38.1, R45.1, SW3.2, U6.2 (3V3), U7.12 (AVDD), U7.13 (DVDD), U8.12 (AVDD), U8.13 (DVDD); also elsewhere on the board
+5V: R42.1; also elsewhere on the board
+BATT: R43.1; also elsewhere on the board
/MCU_And_Peripherals/I2C_SDA_LED_K: D12.1 (K), R28.1
/MCU_And_Peripherals/LED_01_K: D13.1 (K), R29.1
/MCU_And_Peripherals/LED_02_K: D14.1 (K), R30.1
/MCU_And_Peripherals/SPI_CS_LED_0_K: D7.1 (K), R31.1
/MCU_And_Peripherals/SPI_CS_LED_1_K: D6.1 (K), R33.1
/MCU_And_Peripherals/SPI_CS_LED_EXT_K: D5.1 (K), R35.1
/MCU_And_Peripherals/UART0_RX_LED_K: D8.1 (K), R24.1
/MCU_And_Peripherals/UART0_TX_LED_K: D9.1 (K), R25.1
/MCU_And_Peripherals/UART1_RX_LED_K: D10.1 (K), R26.1
/MCU_And_Peripherals/UART1_TX_LED_K: D11.1 (K), R27.1
ANA_IN_01: R57.1; also elsewhere on the board
ANA_IN_01_UC: C27.1, D15.1 (K), R57.2, R59.1, TP33.1, U8.11 (AIN0/REFP1)
ANA_IN_02: R58.1; also elsewhere on the board
ANA_IN_02_UC: C28.1, D16.1 (K), R58.2, R60.1, TP34.1, U8.10 (AIN1)
ANA_IN_03: R62.1; also elsewhere on the board
ANA_IN_03_UC: C33.1, D20.1 (K), R62.2, R68.1, TP36.1, U8.7 (AIN2)
ANA_IN_04: R61.1; also elsewhere on the board
ANA_IN_04_UC: C32.1, D19.1 (K), R61.2, R67.1, TP35.1, U8.6 (AIN3/REFN1)
BATT_SENSE: C24.1, R43.2, R47.1, U7.7 (AIN2)
BOOT: C20.1, Q4.3 (D), R38.2, SW2.1, U6.27 (GPIO0/BOOT)
CH340_DTR: Q4.2 (S), R36.1; also elsewhere on the board
CH340_RTS: Q3.2 (S), R41.1; also elsewhere on the board
DIG_IO_01: R63.2, R69.1; also elsewhere on the board
DIG_IO_01_UC: C30.1, D17.3 (COM), R63.1, R65.1, TP23.1, U6.20 (GPIO12/TOUCH12/ADC2_CH1/FSPICLK/FSPIIO6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)
DIG_IO_02: R64.2, R70.1; also elsewhere on the board
DIG_IO_02_UC: C31.1, D18.3 (COM), R64.1, R66.1, TP24.1, U6.21 (GPIO13/TOUCH13/ADC2_CH2/FSPIQ/FSPIIO7/S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)
DIG_IO_03: R75.2, R79.1; also elsewhere on the board
DIG_IO_03_UC: C34.1, D23.3 (COM), R75.1, R77.1, TP25.1, U6.22 (GPIO14/TOUCH14/ADC2_CH3/FSPIWP/FSPIDQS/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)
DIG_IO_04: R76.2, R80.1; also elsewhere on the board
DIG_IO_04_UC: C35.1, D24.3 (COM), R76.1, R78.1, TP28.1, U6.23 (GPIO21)
DIG_OUT_01: Q5.3 (D); also elsewhere on the board
DIG_OUT_01_UC: R50.1, TP15.1, U6.4 (GPIO4/TOUCH4/ADC1_CH3)
DIG_OUT_02: Q6.3 (D); also elsewhere on the board
DIG_OUT_02_UC: R51.1, TP16.1, U6.5 (GPIO5/TOUCH5/ADC1_CH4)
GND: C16.1, C17.1, C18.2, C19.2, C20.2, C21.2, C22.1, C23.2, C24.2, C25.2, C26.2, C27.2, C28.2, C29.1, C30.2, C31.2, C32.2, C33.2, C34.2, C35.2, D15.2 (A), D16.2 (A), D17.1 (A), D18.1 (A), D19.2 (A), D20.2 (A), D21.1 (K), D22.1 (K), D23.1 (A), D24.1 (A), D25.1 (K), D26.1 (K), Q5.2 (S), Q6.2 (S), R29.2, R30.2, R40.2, R46.2, R47.2, R48.2, R54.2, R55.2, R59.2, R60.2, R65.2, R66.2, R67.2, R68.2, R77.2, R78.2, SW1.2, SW2.2, TH1.2, U6.1 (GND), U6.40 (GND), U6.41 (GND), U7.3 (CLK), U7.4 (DGND), U7.5 (AVSS), U8.3 (CLK), U8.4 (DGND), U8.5 (AVSS); also elsewhere on the board
I2C_SCL: TP13.1, U6.39 (GPIO1/TOUCH1/ADC1_CH0); also elsewhere on the board
I2C_SDA: R28.2, TP14.1, U6.38 (GPIO2/TOUCH2/ADC1_CH1); also elsewhere on the board
JTAG_TCK: U6.32 (MTCK/GPIO39/CLK_OUT3/SUBSPICS1); also elsewhere on the board
JTAG_TDI: U6.34 (MTDI/GPIO41/CLK_OUT1); also elsewhere on the board
JTAG_TDO: U6.33 (MTDO/GPIO40/CLK_OUT2); also elsewhere on the board
JTAG_TMS: U6.35 (MTMS/GPIO42); also elsewhere on the board
LED_01: D13.2 (A), TP29.1, U6.31 (GPIO38/FSPIWP/SUBSPIWP)
LED_02: D14.2 (A), TP32.1, U6.24 (GPIO47/SPICLK_P/SUBSPICLK_P_DIFF)
unnamed: C19.1, R39.2, SW1.1
unnamed: D21.2 (A), R69.2
unnamed: D22.2 (A), R70.2
unnamed: D25.2 (A), R79.2
unnamed: D26.2 (A), R80.2
unnamed: Q3.1 (G), R36.2
unnamed: Q4.1 (G), R41.2
unnamed: Q5.1 (G), R50.2, R54.1
unnamed: Q6.1 (G), R51.2, R55.1
unnamed: TP17.1, U6.6 (GPIO6/TOUCH6/ADC1_CH5)
unnamed: TP18.1, U6.7 (GPIO7/TOUCH7/ADC1_CH6)
unnamed: TP19.1, U6.12 (GPIO8/TOUCH8/ADC1_CH7/SUBSPICS1)
unnamed: TP20.1, U6.17 (GPIO9/TOUCH9/ADC1_CH8/FSPIHD/SUBSPIHD)
unnamed: TP21.1, U6.18 (GPIO10/TOUCH10/ADC1_CH9/FSPICS0/FSPIIO4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)
unnamed: TP22.1, U6.19 (GPIO11/TOUCH11/ADC2_CH0/FSPID/FSPIIO5/S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)
unnamed: R34.2, U6.13 (GPIO19/U1RTS/ADC2_CH8/CLK_OUT2/USB_D-)
unnamed: R32.2, U6.14 (GPIO20/U1CTS/ADC2_CH9/CLK_OUT1/USB_D+)
unnamed: TP30.1, U6.26 (GPIO45)
unnamed: TP31.1, U6.16 (GPIO46)
unnamed: R52.1, U7.16 (DIN)
unnamed: R53.1, U7.15 (DOUT/~DRDY)
unnamed: R49.1, U7.1 (SCLK)
unnamed: R56.1, U7.2 (~CS)
unnamed: R72.1, U8.16 (DIN)
unnamed: R73.1, U8.15 (DOUT/~DRDY)
unnamed: R71.1, U8.1 (SCLK)
unnamed: R74.1, U8.2 (~CS)
PCB_TEMP: C26.1, R45.2, TH1.1, U7.11 (AIN0/REFP1)
PWR_SENSE: C25.1, R44.2, R48.1, U7.6 (AIN3/REFN1)
RST: C18.1, Q3.3 (D), R37.2, R39.1, U6.3 (EN); also elsewhere on the board
SPI_CS_ADC0: R31.2, R56.2, TP11.1, U6.8 (GPIO15/U0RTS/ADC2_CH4/XTAL_32K_P)
SPI_CS_ADC1: R33.2, R74.2, TP12.1, U6.9 (GPIO16/U0CTS/ADC2_CH5/XTAL_32K_N)
SPI_CS_EXT: R35.2, U6.25 (GPIO48/SPICLK_N/SUBSPICLK_N_DIFF); also elsewhere on the board
SPI_MISO: R53.2, R73.2, U6.30 (SPIDQS/GPIO37/FSPIQ/SUBSPIQ); also elsewhere on the board
SPI_MOSI: R52.2, R72.2, U6.28 (SPIIO6/GPIO35/FSPID/SUBSPID); also elsewhere on the board
SPI_SCLK: R49.2, R71.2, U6.29 (SPIIO7/GPIO36/FSPICLK/SUBSPICLK); also elsewhere on the board
UART0_UC_RX: R24.2, TP10.1, U6.36 (U0RXD/GPIO44/CLK_OUT2); also elsewhere on the board
UART0_UC_TX: R25.2, TP9.1, U6.37 (U0TXD/GPIO43/CLK_OUT1); also elsewhere on the board
UART1_UC_RX: R26.2, TP27.1, U6.11 (GPIO18/U1RXD/ADC2_CH7/CLK_OUT3); also elsewhere on the board
UART1_UC_TX: R27.2, TP26.1, U6.10 (GPIO17/U1TXD/ADC2_CH6); also elsewhere on the board
USB_D+: R32.1; also elsewhere on the board
USB_D-: R34.1; also elsewhere on the board
USER_BUTTON: C21.1, R40.1, SW3.1, U6.15 (GPIO3/TOUCH3/ADC1_CH2)
V_IN: R44.1; also elsewhere on the board

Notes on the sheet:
ESP32 LEDs
This IC basically uses SPI communication, where CPOL = 0 and CPHA = 1. SCLK idles low and data are launched or changed only on SCLK rising edges, data are latched or read by the master and slave on SCLK falling edge. CS is active low. For more information, see ADS1220 datasheet chapter 9.1.1 "Seria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
NTC thermistor placed on the PCB for diagnostic measurement
UART activity LEDs
SPI activity LEDs
Measures supply voltages. Make sure to use higher resistance so we don't drain the battery.
Analog inputs have a 470R input resistance, so in the case of over voltage when current is flowing trough the 3.6V zener, there is no overcurrent. This 470R resistance should not affect the ADC measurements, but in case it does, we should add a quality external ADC IC. There is also a pulldown resi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
To ensure that the power supply to the ESP32-S3 chip is stable during power-up, it is advised to add an RC delay circuit at the EN pin. The recommended setting for the RC delay circuit is usually R = 10 kΩ and C = 1 μF, for 10ms delay
I2C activity LED
UART TX and RX pins are active low, so when the communication is active, the lines will be pulled low, and LEDs will light up
I2C is active low, so when the communication is active, the lines will be pulled low, and LEDs will light up
GPIO6 - GPIO11 Reserved for internal flash
ADCs chip select is active low
ESP32-S3 has four bootstrapping pins: • GPIO0 Default: pullup to HIGH, to boot from SPI flash. Low to enter flash mode • GPIO45 Default: pulldown Selects SPI voltage, when LOW 3.3V, when HIGH 1.8V • GPIO46 Default: pulldown When GPIO0 is HIGH, this pin doesnt matter. When GPIO0 is LOW, this pin mus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
MOSI - FSPID MISO - FSPIQ SCK - FSPICLK
USB TO UART PROGRAMMING
ADC via SPI ADS1220IPWR
DIRECT USB
User interaction
*bootstrap
JTAG DEBUGGING
MCU
AO3400A N MOSFET
BAT54S Dual diode package UV/OV prot.
User button
CH340 USB TO UART RST/BOOT CONTROL
ESP32-S3-WROOM-1-N16R8
Decoupling cap
WiFi status
Reset button
ADC - on-board sensors
Blinky LED
On-board sensors
Decoupling caps
Status LEDs
Digital I/O
Open drain and PWM outputs
GSM MODULE
ADC - analog inputs
Analog inputs

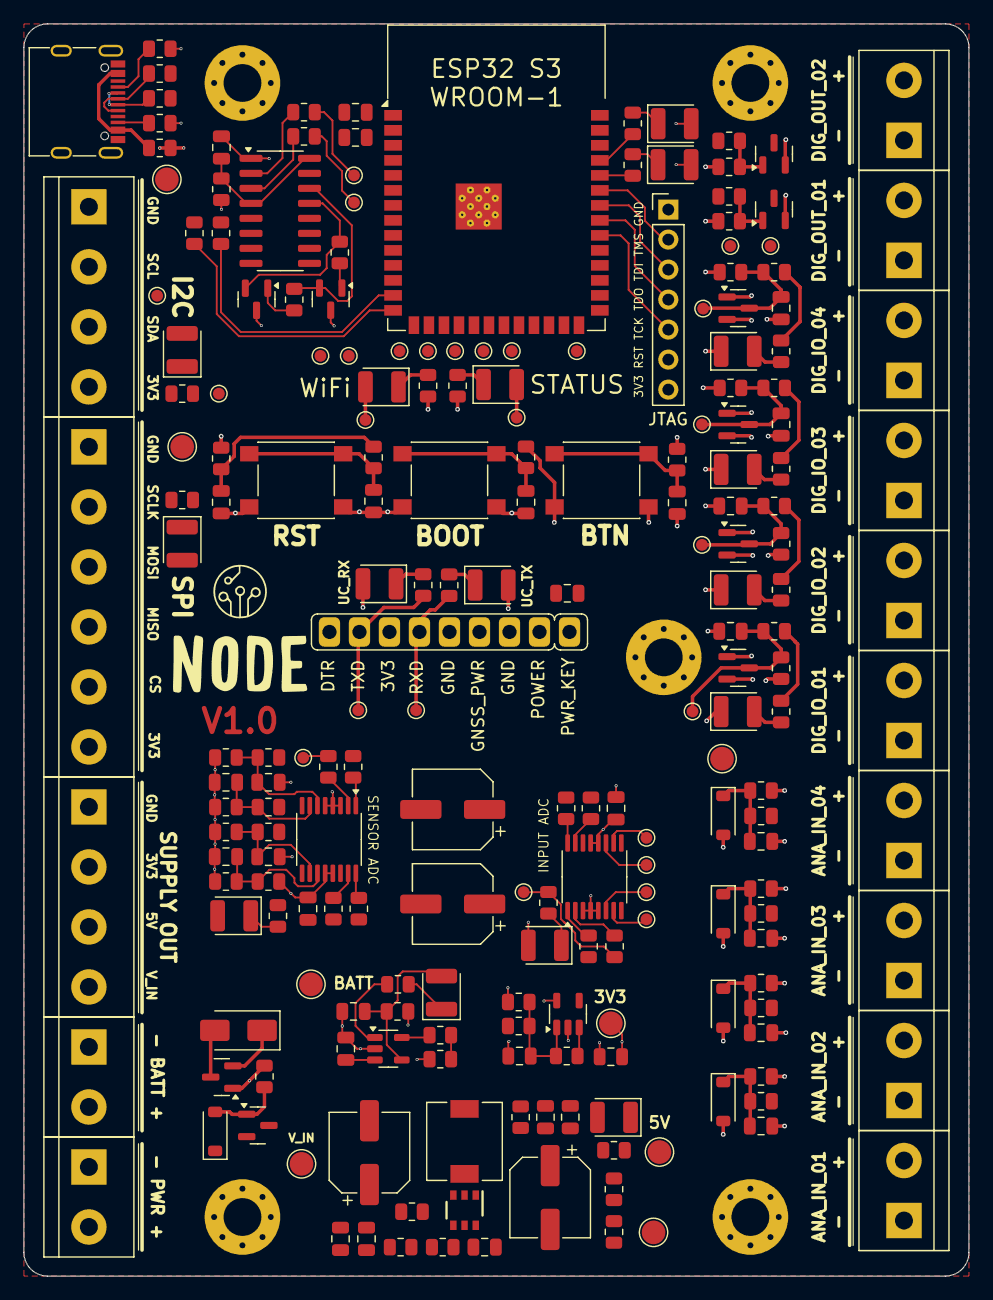
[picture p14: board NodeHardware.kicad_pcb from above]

Board: 4 copper layers, 80.0 x 106.0 mm, 219 parts (0 on the bottom side), 116 nets.

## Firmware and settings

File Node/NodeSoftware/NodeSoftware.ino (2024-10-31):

/**
 * We create an array of pointers to 'generic drivers' which include all sensors, networking and system stuff,
 * then we call 'Handle' function for each of them every 1s. Each driver is given a JSON object as parameter,
 * where they note down any values that need to be shared via MQTT. Networking is called last so it sends the 
 * complete json string via MQTT.
 *
 * @todo Check for buffer overflows or anything similar. We get restarting of the device from time to time (sometimes often)
 * @todo Maybe tansition to multicore approach: one core for WiFi/MQTT/OTA, other core for real-time sensor gathering!
 * @todo For sensors, at begining try pulling the sensor to high, and to low, and see if the input really changes. 
 *       Basically do open load detect, and ignore the sensor in case nothing connected.
 */

/* System includes */
#include <ArduinoJson.h>
#include "config.h"

/* All the sensors and drivers */
#include "generic_driver.h" /* Used to define array of 'Driver' classes */
#include "network_driver.h" /* Handles all network related functions (WiFi, MQTT) */
#include "sensor_air_quality.h"
#include "sensor_bmp280.h"
#include "sensor_dht22.h"
#include "sensor_light.h"
#include "sensor_pcb_temp.h"
#include "sensor_presence.h"
#include "sensor_system_health.h" /* Monitors SW stuff: cycle time, free heap... */

/***********************************************
 *  VARIABLES
 ***********************************************/

uint32_t last_main_cycle = 0;

/***********************************************
 *  Objects (drivers, sensors, JSON...)
 ***********************************************/

JsonDocument main_json_message;

Driver *drivers[] = 
{
  new SystemHealthSensor(SYSTEM_STATUS_LED_PIN, DEBUG_CYCLE_TIME), /* Should always be first (so reading millis() will be accurate) */
  new AirQualitySensor(AIR_QUALITY_SENSOR_PIN),
  new BMP280Sensor(/* Uses I2C pins 8 (SDA) and 9 (SCL) */),
  new DHT22Sensor(DHT22_PIN),
  new LightSensor(LIGHT_SENSOR_PIN),
  new PcbTempSensor(PCB_TEMP_PIN),
  new PresenceSensor(PRESENCE_SENSOR_PIN),
  new NetworkHandler(WIFI_STATUS_LED_PIN, SEND_DELAY) /* Should always be last (to send all gathered data) */
};

/***********************************************
 *  FUNCTION DEFINITIONS
 ***********************************************/

void setup()
{
  Serial.begin(SERIAL_BAUDRATE);

  /* Let's go! Initialize all the given sensors and drivers... */
  for(Driver *driver : drivers)
  {
    (*driver).Init();
  }
}

void loop()
{
  /* Main loop: handle every x milliseconds */
  uint32_t now = millis();
  if (now - last_main_cycle >= MAIN_CYCLE_TIME)
  {
    last_main_cycle = now;

    /* Call each drivers handle function */
    for(Driver *driver : drivers)
    {
      (*driver).Handle(&main_json_message);
    }
  }
}

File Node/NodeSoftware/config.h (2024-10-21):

#ifndef FLEX_CONFIG_H
#define FLEX_CONFIG_H

/*******************************************************/
/*** TIMING DEFINES ************************************/
/*******************************************************/

/* Baudrate used for serial communication */
#define SERIAL_BAUDRATE (115200)

/* Cycle time of the main program loop (ms). Set to 1s, as we don't need faster handling */
/* Other sensors might rely on thei 'Handle' functions being called exactly every 1s (led blinking, active wait, etc.) */
/* Usually more than 100ms is needed to do everything in a loop, but that has to be measured for specifc scenarios */
#define MAIN_CYCLE_TIME (1000)

/* How much to wait between two MQTT frames (ms) */
#define SEND_DELAY (300 * 1000)        /* Every 5min == 300s */

/* Cycle time of the debug loop (printing log to serial) in ms */
#define DEBUG_CYCLE_TIME (5 * 1000)    /* Print to Serial every 5s */


/*******************************************************/
/*** PIN DEFINES ***************************************/
/*******************************************************/

/* Pin to which the system status LED is connected */
#define SYSTEM_STATUS_LED_PIN 35

/* Pin to which the system status LED is connected */
#define WIFI_STATUS_LED_PIN 4

/* DHT22 connected to pin GPIO20 */
#define DHT22_PIN  20

/* NTC thermistor to measure PCB temp is connected to... */
#define PCB_TEMP_PIN 18

/* Presence sensor is connected to... */
#define PRESENCE_SENSOR_PIN 2

/* Light dependent resistor is connected to... */
#define LIGHT_SENSOR_PIN 1

/* Pin to which the MQ-2 gas sensor is connected */
#define AIR_QUALITY_SENSOR_PIN 5

/* BMP-280 is connected via I2C: */
/* SDA - GPIO8 */
/* SCL - GPIO9 */


#endif /* #ifndef FLEX_CONFIG_H */

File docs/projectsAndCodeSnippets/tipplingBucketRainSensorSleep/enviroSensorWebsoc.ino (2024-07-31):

#include <Arduino.h>
#include <esp_sleep.h>
#include <esp_timer.h>
#include "esp_netif.h"
#include <WiFi.h>
#include "time.h"
#include "esp_sntp.h"
#include "globalVars.h"
#include "esp32s3/rom/rtc.h"
#include "manageConnection.h"
#include "ntpSync.h"
#include "tipplingBucketRainSens.h"

void setup() {

  Serial.begin(115200);
  Serial.println("woke up!");
  Serial.println(esp_sleep_get_wakeup_cause());


  mcuStateInfoESP32.wakeUpCause = esp_sleep_get_wakeup_cause();
  mcuStateInfoESP32.resetCause  = esp_reset_reason();

  // Set up timer wakeup
  /* esp_sleep_enable_timer_wakeup(TIMER_WAKEUP_TIME_US);*/

  if (2u == mcuStateInfoESP32.wakeUpCause) {

    uint8_t tipplingBucketCurrentState = 2u;
    do {
      tipplingBucketCurrentState = RainSens::getDigInDebounced(200);
      vTaskDelay(10 / portTICK_PERIOD_MS);
    } while (2u == tipplingBucketCurrentState);
    /* RTC ext wakeup */
    if (tipplingBucketCurrentState != rainData.tipplingBucketDigInPrevious) {

      rainData.tipplingBucketDigInPrevious = tipplingBucketCurrentState;
      rainData.tipplingBucketCount++;
      rainData.tipplingBucketCountHour++;
      rainData.tipplingBucketCountDay++;
      Serial.print("tipplingBucket change was counted. back to sleep. count: ");
      Serial.println(rainData.tipplingBucketCount);
    }

    WiFi.disconnect();
    uint64_t unixNextWakeUpTime = mcuStateInfoESP32.nextScheduledWakeUp;

    if (unixNextWakeUpTime >= (mcuStateInfoESP32.unixSendNextReportAt - SEND_REPORT_EARLY_WAKE_SECS)) {
      Serial.println(" sleep will be cut short because of send!");
      unixNextWakeUpTime = (mcuStateInfoESP32.unixSendNextReportAt - SEND_REPORT_EARLY_WAKE_SECS);
    }


    if (unixNextWakeUpTime > (getEpoch() + MINIMUM_GOTO_SLEEP_SECONDS)) {
      Serial.print("going to sleep for [s]: ");
      Serial.println(unixNextWakeUpTime - getEpoch());
      /* @TODO: fix transition detection on startup */
      esp_sleep_enable_ext0_wakeup(GPIO_NUM_1, (0u == rainData.tipplingBucketDigInPrevious) ? 1u : 0u); //1 = High, 0 = Low
      esp_deep_sleep((unixNextWakeUpTime - time(NULL)) * 1000000);
    }
    else {
      Serial.println("[Er] Sleep aborted because time is to small");
    }
  }
  else if (4u == mcuStateInfoESP32.wakeUpCause) {
    Serial.println("wakeup by timer:");
  }
}

void loop() {

  int8_t networkActive = NETWORK_wlanConnect();
  if (networkActive == 0) {
    NTP_updateTimeFromNTP();
  }

  printLocalTime();



    /*struct tm* current_time = localtime(pgetEpoch());*/
    struct tm* current_time = getLocalTime(getEpoch());

    current_time->tm_min = 0;
    current_time->tm_sec = 0;
    (current_time->tm_hour == 23) ? (current_time->tm_hour = 0) : (current_time->tm_hour++);

    rainData.unixStartOfNextHour = (uint32_t)mktime(current_time);

    current_time = getLocalTime(getEpoch());
    current_time->tm_min = 0;
    current_time->tm_sec = 0;
    current_time->tm_hour = 0;
    current_time->tm_mday++;

    rainData.unixStartOfNextDay = (uint32_t)mktime(current_time);

    mcuStateInfoESP32.nextScheduledWakeUp = getEpoch() + 30;



    current_time = getLocalTime(getEpoch());;
    uint32_t secondsNextSend = (current_time->tm_hour * 3600) + (current_time->tm_min * 60) + current_time->tm_sec;
    Serial.print("current time secs: ");
    Serial.println(secondsNextSend);

    secondsNextSend = secondsNextSend + SEND_REPORT_EVERY_SECS;
    secondsNextSend -= secondsNextSend % SEND_REPORT_EVERY_SECS;
    Serial.print("next increment secs: ");
    Serial.println(secondsNextSend);

    current_time->tm_mday += secondsNextSend / (3600 * 24);
    secondsNextSend %= (3600 * 24);
    current_time->tm_hour = secondsNextSend / 3600;
    secondsNextSend %= 3600;
    current_time->tm_min = secondsNextSend / 60;
    secondsNextSend %= 60;
    current_time->tm_sec = secondsNextSend;

    mcuStateInfoESP32.unixSendNextReportAt = (uint32_t)mktime(current_time);
    Serial.print("next report at: ");
    Serial.println((mcuStateInfoESP32.unixSendNextReportAt - getEpoch()));

    Serial.print("bucket count: ");
    Serial.println(rainData.tipplingBucketCount);

    printLocalTime();
    Serial.println(getEpoch());
    Serial.println(rainData.unixStartOfNextHour - getEpoch());
    Serial.println(rainData.unixStartOfNextDay - getEpoch());
  
  
    vTaskDelay(1000 / portTICK_PERIOD_MS);

  mcuReadyForSleep = true;

  if (true == mcuReadyForSleep) {

    /*WiFi.disconnect();*/
    uint64_t unixNextWakeUpTime = mcuStateInfoESP32.nextScheduledWakeUp;

    if (getEpoch() < 1717848248) {
      Serial.println("No correct ntp time fount!");
    }
    else {
      if (unixNextWakeUpTime >= (mcuStateInfoESP32.unixSendNextReportAt - SEND_REPORT_EARLY_WAKE_SECS)) {
        Serial.println(" sleep will be cut short because of send!");
        unixNextWakeUpTime = (mcuStateInfoESP32.unixSendNextReportAt - SEND_REPORT_EARLY_WAKE_SECS);
      }
    }

    if (unixNextWakeUpTime > (getEpoch() + MINIMUM_GOTO_SLEEP_SECONDS)) {
      Serial.print("going to sleep for [s]: ");
      Serial.println(unixNextWakeUpTime - getEpoch());
      /* @TODO: fix transition detection on startup */
      esp_sleep_enable_ext0_wakeup(GPIO_NUM_1, (0u == rainData.tipplingBucketDigInPrevious) ? 1u : 0u); //1 = High, 0 = Low
      esp_deep_sleep((unixNextWakeUpTime - time(NULL)) * 1000000);
    }
    else {
      Serial.println("[Er] Sleep aborted because time is to small");
    }
  }

}

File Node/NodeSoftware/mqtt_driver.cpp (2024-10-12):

/* System includes */
#include <WiFi.h>
#include <PubSubClient.h>
#include <ArduinoJson.h>
#include "config.h"
#include "admin.h"

/* Own includes */
#include "mqtt_driver.h"

/***********************************************
 *  VARIABLES
 ***********************************************/

#if STATUS_LED_PRESENT
  /* Pretty self explanitory */
  long long last_led_blink_time = 0;
#endif

#if MQTT_PRESENT
  mqtt_states_e mqtt_state = mqtt_idle;
  WiFiClient espClient;
  PubSubClient client(espClient);

  /* Keep track of the time when we last send an MQTT message */
  long long last_send_time = 0;
  long long active_delay_start_time = 0;
#endif

/***********************************************
 *  FUNCTION DEFINITIONS
 ***********************************************/

#if MQTT_PRESENT
  /** Callback function, which will be called when we receive a message on a topic we are subscribed to */
  void callback(char *topic, byte *message, unsigned int length)
  {
    Serial.println();
    Serial.print("Message arrived on topic: '");
    Serial.print(topic);
    Serial.print("'. Message: ");
    String messageTemp;

    for (int i = 0; i < length; i++)
    {
      Serial.print((char)message[i]);
      messageTemp += (char)message[i];
    }
    Serial.println();
  }
#endif

void mqtt_setup()
{
  #if STATUS_LED_PRESENT
    pinMode(STATUS_LED_PIN, OUTPUT);
    digitalWrite(STATUS_LED_PIN, HIGH);
  #endif

  #if MQTT_PRESENT
    /* Initially, we only have to kick off the state machine, and it will go its way: */
    mqtt_state = mqtt_wifi_start;
  #endif
}

void mqtt_loop(JsonDocument* json_message)
{
  /* Get current time. Needed later... */
  long long now = micros();

  /* Store our device name in the JSON (no matter what) */
  (*json_message)["name"] = mqtt_devicename;

  /* Now for some WiFi/MQTT state machine stuff... */
  #if MQTT_PRESENT
    switch(mqtt_state)
    {
      /***********************************************
      *  Idle: main functonality code
      ***********************************************/
      case (mqtt_idle):
        /* If we lost MQTT connection, try to connect again! */
        if (!client.connected())
        {
          mqtt_state = mqtt_mqtt_start;
          break;
        }

        /* MQTT client handle */
        client.loop();
        
        /* Blink the blinky every now and then... */
        #if STATUS_LED_PRESENT
          if (now - last_led_blink_time > LED_BLINK_DELAY)
          {
            last_led_blink_time = now;

            /* Blink the LED */
            digitalWrite(STATUS_LED_PIN, !digitalRead(STATUS_LED_PIN));
          }
        #endif

        /* Did the time come to send the data? */
        if (now - last_send_time > SEND_DELAY)
        {
          /* Keep track of time */
          last_send_time = now;

          char tempString[MQTT_MESSAGE_MAX_LENGTH];
          serializeJson((*json_message), tempString);
          Serial.print("Sending MQTT message: ");
          Serial.println(tempString);
          client.publish(mqtt_publish_topic, tempString);
        }
        break;

      /***********************************************
      *  WiFi related states:
      ***********************************************/
      case (mqtt_wifi_start):
        /* We start by connecting to a WiFi network */
        Serial.print("\nConnecting to ");
        Serial.println(wifi_ssid);
        WiFi.begin(wifi_ssid, wifi_password);
        mqtt_state = mqtt_wifi_connecting;
        break;

      case (mqtt_wifi_connecting):
        /* If still not connected, blink the LED every once in a while */
        if(WiFi.status() != WL_CONNECTED)
        {
          /* Using 'smart' active delay! */
          if (now - active_delay_start_time > WIFI_CONNECT_LED_BLINK_DELAY)
          {
            active_delay_start_time = now;
            Serial.print(".");
            digitalWrite(STATUS_LED_PIN, !digitalRead(STATUS_LED_PIN)); /* This will toggle the LED every 200ms while trying to connect to WiFi */
          }
        }
        else
        {
          /* Wow, we connected to wifi! Onwards! */
          mqtt_state = mqtt_wifi_connected;
        }
        break;

      case (mqtt_wifi_connected):
        Serial.println("\nWiFi connected");
        Serial.println("IP address: ");
        Serial.println(WiFi.localIP());
        mqtt_state = mqtt_mqtt_start;
        break;

      /***********************************************
      *  MQTT related states:
      ***********************************************/
      case (mqtt_mqtt_start):
        client.setServer(mqtt_server, 1883);
        client.setCallback(callback);
        mqtt_state = mqtt_mqtt_connecting;
        break;

      case (mqtt_mqtt_connecting):
        if (!client.connected())
        {
          /* Actively wait before trying re-connection */
          if (now - active_delay_start_time > WIFI_CONNECT_LED_BLINK_DELAY)
          {
            active_delay_start_time = now;
            Serial.print("Attempting MQTT connection... ");
            if (client.connect(mqtt_devicename, mqtt_username, mqtt_password))
            {
              Serial.println("connected");
              client.subscribe(mqtt_subscribe_topic);
            }
            else
            {
              Serial.print("failed, return code = ");
              Serial.print(client.state());
              Serial.println(". Trying again soon...");
              digitalWrite(STATUS_LED_PIN, !digitalRead(STATUS_LED_PIN));
            }
          }
        }
        else
        {
          mqtt_state = mqtt_mqtt_connected;
        }
        break;

      case (mqtt_mqtt_connected):
        mqtt_state = mqtt_idle;
        break;

      /***********************************************
      *  Errors:
      ***********************************************/
      case (mqtt_error):
        /* Do the unthinkable :o */
        ESP.restart();
        break;

      default:
        /* Impossible! */
        mqtt_state = mqtt_error;
        break;
    }
  #endif
}

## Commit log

2024-07-30 Added basic KiCAD project and started adding items
    [MCU_And_Peripherals.kicad_sch, NodeHardware.kicad_pcb, NodeHardware.kicad_sch]
2024-07-31 Finish all the basic SCHM needed for the ESP32
    [MCU_And_Peripherals.kicad_sch, NodeHardware.kicad_pcb, NodeHardware.kicad_sch]
2024-07-31 Finish first version of inputs
    [MCU_And_Peripherals.kicad_sch, NodeHardware.kicad_sch]
2024-07-31 added some useful reference materials for ESP32 S3 deep sleep RTC, extPin, timer, wake up implementation, added application notes for SIM7000 GSM modem
2024-07-31 added my custom kicad components, and esp_board project to be a reference as it has a very similar concept to this project.
2024-07-31 added some comments and sim module to schematic
    [MCU_And_Peripherals.kicad_sch, NodeHardware.kicad_pcb, NodeHardware.kicad_sch]
2024-08-04 Add a comment
    [MCU_And_Peripherals.kicad_sch, NodeHardware.kicad_pcb]
2024-08-04 Cleanup and update gitignore
    [MCU_And_Peripherals.kicad_sch, NodeHardware.kicad_pcb, NodeHardware.kicad_sch]
2024-08-04 Schm cleanup and commenting
    [MCU_And_Peripherals.kicad_sch, NodeHardware.kicad_sch]
2024-08-28 Update SCHM (psu, cleanup), add datasheets
    [MCU_And_Peripherals.kicad_sch, NodeHardware.kicad_sch]
2024-08-31 Continue updating schm for initial version
    [MCU_And_Peripherals.kicad_sch, NodeHardware.kicad_sch]
2024-08-31 Continue schm update, slow progress
    [MCU_And_Peripherals.kicad_sch, NodeHardware.kicad_pcb, NodeHardware.kicad_sch]
2024-09-01 Never ending SCHM design
    [MCU_And_Peripherals.kicad_sch, NodeHardware.kicad_pcb, NodeHardware.kicad_sch]
2024-09-17 Halfway working on PCB for Node
    [MCU_And_Peripherals.kicad_sch, NodeHardware.kicad_pcb, NodeHardware.kicad_sch]
2024-09-21 Add sample code for ESP32 Node
2024-09-21 Continue updating PCB (main form)
    [MCU_And_Peripherals.kicad_sch, NodeHardware.kicad_pcb, NodeHardware.kicad_sch]
2024-09-24 Finish v1 of PCB layout
    [MCU_And_Peripherals.kicad_sch, NodeHardware.kicad_pcb, NodeHardware.kicad_sch]
2024-10-07 Update SW side of the Node
    Still a lot of cleanup and work remains
    [NodeHardware.kicad_pcb, ntc_lookup.xlsx]
2024-10-12 Update SW side
    Still bugs present
    [NodeSoftware.ino, config.h, mqtt_driver.cpp]
2024-10-21 Update SW a lot
    Using classes now, and dynamically creating all driver/sensors
    [ntc_lookup.xlsx]
